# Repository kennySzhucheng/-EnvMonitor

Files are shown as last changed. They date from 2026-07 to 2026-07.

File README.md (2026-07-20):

# EnvMonitor — 智能环境监测站

> STM32F103C8T6 + FreeRTOS + ESP8266 桌面环境监测终端 | 练习项目

一个从零开始搭建的嵌入式 IoT 项目：裸机固件 → FreeRTOS 重构 → KiCad 画板 → 嘉立创打样，走完嵌入式产品全流程。

---

## 📸 实物展示

> ⏳ PCB 已下单，等待到货焊接后补图。

---

## ✨ 功能

| 模块 | 作用 |
|---|---|
| 🌡️ **DHT22** | 温湿度传感器，单总线(1-Wire)通信，精度 ±0.5°C / ±2%RH，挂在 PA0 上 |
| ☀️ **BH1750** | 环境光强度传感器，I²C 接口，0~65535 lux 量程，和 OLED 共用 PB6/PB7 |
| 📏 **HC-SR04** | 超声波测距模块，探测前方物体距离，用于"有人靠近"检测，PB0 发触发信号、PB1 输入捕获回波 |
| 🖥️ **OLED SSD1306** | 0.96 寸 I²C 显示屏，5 页菜单循环切换(温湿度/光照/距离/WiFi/系统信息) |
| 📡 **ESP8266-01S** | WiFi 模块，通过 UART1(PA9/PA10) 走 AT 指令，HTTP GET 方式每 60s 上传一次 ThingSpeak |
| 🚨 **三色 LED** | 红色(高温>35°C)、黄色(湿度<30%)、绿色(有人靠近<30cm)，分别接 PB12/13/14 |
| 🔔 **蜂鸣器** | 5V 有源模块，出现报警条件时由 BuzzerTask 队列驱动蜂鸣 |
| 🎛️ **三按键** | KEY1 页面切换 / KEY2 确认 / KEY3 返回，PA4/5/6，消抖电容 + 10kΩ 外部上拉 |
| ⏱️ **FreeRTOS** | 6 个任务抢占式调度，3 个互斥量保护共享资源，2 条队列做任务间通信 |
| 🛡️ **自定义 PCB** | KiCad 10 设计，80×60mm 双面板，全插件 27 元件，双面 GND 铺铜 |

---

## 🧱 硬件架构

```
                    ┌──────────────────────────────────┐
                    │        STM32F103C8T6 (72MHz)     │
                    │           Blue Pill 核心板         │
                    │                                  │
    DHT22 ──────────┤ PA0 (1-Wire)                     │
    KEY1~3 ─────────┤ PA4/PA5/PA6 (GPIO Input)        │
    ESP8266 ────────┤ PA9/PA10 (USART1, 115200bps)     │
    HC-SR04 ────────┤ PB0(Trig) / PB1(Echo, TIM3_CH4) │
    OLED+BH1750 ────┤ PB6/PB7 (I2C1, 共用总线)          │
    LED_R/Y/G ──────┤ PB12/PB13/PB14 (GPIO Output)     │
    Buzzer ─────────┤ PB15 (GPIO Output, 直连模块IO)    │
                    └──────────────────────────────────┘

    电源: USB 5V → Blue Pill → AMS1117 → 3.3V（全板供电来自 USB）
```

---

## 📐 引脚分配

| 引脚 | 外设 | 功能 |
|---|---|---|
| PA0 | DHT22 | 1-Wire 单总线 |
| PA4/PA5/PA6 | KEY1/KEY2/KEY3 | 按键输入(10kΩ 上拉) |
| PA9/PA10 | ESP8266 | USART1 TX/RX |
| PB0 | HC-SR04 Trig | 触发信号 |
| PB1 | HC-SR04 Echo | TIM3_CH4 输入捕获 |
| PB6/PB7 | OLED + BH1750 | I2C1 SCL/SDA（共用总线） |
| PB12/PB13/PB14 | LED_R/Y/G | 报警指示灯 |
| PB15 | Buzzer | 有源蜂鸣器模块 IO |
| PA13/PA14 | SWDIO/SWCLK | ST-Link 调试（保留） |

---

## 🖥️ 软件架构

```
                    ┌───────────────┐
                    │   FreeRTOS    │
                    │  V10.3.1      │
                    ├───────┬───────┤
                    │ 互斥量 ×3     │  队列 ×2
                    │ I2C / Data   │  Button → Display
                    │ / UART       │  Alarm → Buzzer
                    └───────┴───────┘
                           │
    ┌──────────────────────┼──────────────────────┐
    │                      │                      │
┌───▼──────┐  ┌──────▼─────┐  ┌────────▼───────┐
│SensorTask│  │DisplayTask │  │  CloudTask      │
│ (5s)     │  │ (1s)       │  │  (60s)          │
│ Prio:3   │  │ Prio:2     │  │  Prio:1         │
│          │  │             │  │                 │
│ DHT22    │  │ OLED 5页   │  │ ESP8266 AT指令  │
│ BH1750   │  │ 菜单渲染    │  │ HTTP GET        │
│ HC-SR04  │  │             │  │ ThingSpeak ☁️   │
└──────────┘  └─────────────┘  └─────────────────┘

┌──────────┐  ┌──────────────┐  ┌──────────────┐
│AlarmTask │  │ BuzzerTask   │  │ ButtonTask    │
│ (500ms)  │  │ (事件驱动)    │  │ (20ms)        │
│ Prio:3   │  │ Prio:2       │  │ Prio:2        │
│          │  │              │  │               │
│ 三级报警  │  │ xQueueReceive│  │ 状态机消抖     │
│ 阈值判断  │──▶ 阻塞等待     │  │ 队列发送事件   │
└──────────┘  └──────────────┘  └──────────────┘
```

**任务优先级原则：** 采集 > 报警 > 显示 = 按键 = 蜂鸣 > 上云

---

## 📦 物料清单 (BOM)

### PCB 焊接件（27个）

| 类型 | 规格 | 数量 | 位号 |
|---|---|---|---|
| 排母 | 1×20P 2.54mm | 2 | H1, H2 |
| 排针 | 1×4P 2.54mm | 3 | J2, J3, J4 |
| 排针 | 2×4P 2.54mm | 1 | J5 |
| 排针 | 1×3P 2.54mm | 1 | LS1 |
| 电阻 | 330Ω 1/4W | 3 | R10, R11, R12 |
| 电阻 | 4.7kΩ 1/4W | 3 | R4, R5, R6 |
| 电阻 | 10kΩ 1/4W | 3 | R7, R8, R9 |
| 瓷片电容 | 100nF (104) | 3 | C18, C19, C20 |
| 电解电容 | 100µF/10V | 2 | C21, C22 |
| LED 3mm | 红/黄/绿 | 3 | D2, D3, D4 |
| 轻触开关 | 6×6mm | 3 | SW2, SW3, SW4 |

### 外接模块（7个）

| 模块 | 数量 |
|---|---|
| STM32F103C8T6 Blue Pill | 1 |
| DHT22 温湿度传感器 | 1 |
| GY-302 光照 (BH1750) | 1 |
| OLED 0.96" SSD1306 | 1 |
| HC-SR04 超声波 | 1 |
| ESP8266-01S WiFi | 1 |
| 5V 有源蜂鸣器模块 | 1 |

> 💰 全部物料实际花费约 **90 元**（含 PCB 打样 20 元 + 模块 51 元 + 分立元件 13 元 + 工具 5 元）。完整清单见 `hardware/pcb/EnvMonitor/BOM_EnvMonitor.md`

---

## 🔧 开发环境

| 工具 | 用途 |
|---|---|
| **Keil MDK5** | 固件编译/烧录 |
| **STM32CubeMX** | 引脚配置 + HAL 代码生成 |
| **STM32CubeF1 V1.8.7** | HAL 库 + FreeRTOS 源码 |
| **ST-Link V2** | 调试/烧录器 |
| **KiCad 10.0** | 原理图 + PCB 设计 |
| **ThingSpeak** | IoT 数据可视化云平台 |

### 编译

1. 用 CubeMX 打开 `EnvMonitor.ioc` 重新生成代码（如需要）
2. `EnvMonitor\MDK-ARM\EnvMonitor.uvprojx` → Keil 打开
3. 确认 Include Paths 包含：`Drivers/*`、`App/`、`FreeRTOS/include`、`FreeRTOS/portable/RVDS/ARM_CM3`
4. Build (F7) → 0 Error → Download (F8)

### ThingSpeak 配置

1. 注册 https://thingspeak.com → Create Channel → 4 Fields
2. 将 Write API Key 填入 `esp8266.h` 中的 `THINGSPEAK_API_KEY`
3. 修改 WiFi 账号密码：`esp8266.h` → `WIFI_SSID` / `WIFI_PASS`

---

## 📂 项目结构

```
EnvMonitor/
├── firmware/               ← 固件源码（裸机版 + FreeRTOS版）
│   ├── Core/               HAL 配置 + main.c
│   ├── Drivers/            8 个外设驱动
│   │   ├── DHT22/          温湿度传感器
│   │   ├── BH1750/         光照传感器
│   │   ├── HC_SR04/        超声波测距
│   │   ├── OLED/           SSD1306 显示 + 字库
│   │   ├── ESP8266/        WiFi + ThingSpeak
│   │   ├── LED/            三色指示灯
│   │   ├── Button/         按键(状态机消抖)
│   │   └── Buzzer/         蜂鸣器
│   └── App/                应用层(状态机/菜单/报警)
│
├── EnvMonitor/             ← Keil + CubeMX 工程
│   ├── Core/               CubeMX 生成(含 main.c)
│   ├── Drivers/            同上 8 驱动 + ST HAL 库
│   ├── App/                6 个 FreeRTOS 任务 + task_shared
│   ├── MDK-ARM/            Keil 工程文件
│   └── EnvMonitor.ioc      CubeMX 项目
│
├── hardware/pcb/EnvMonitor/ ← KiCad PCB 设计
│   ├── EnvMonitor.kicad_*  工程文件
│   ├── BOM_EnvMonitor.md   完整物料清单
│   ├── EnvMonitor_Gerber_Full.zip  嘉立创打样包
│   ├── gerber/             Gerber 源文件(11层)
│   └── analysis/           出厂分析报告
│
└── docs/                   项目文档
    ├── 接线图.md            引脚分配表
    ├── 开发日志.md           设计决策 + 踩坑记录
    ├── 原理图讲解.md
    ├── KiCad入门讲解.md
    ├── PCB布局布线入门.md
    └── FreeRTOS入门讲解.md
```

---

## 📝 开发历程

| 阶段 | 内容 | 状态 |
|---|---|---|
| P0 | 项目规划 + 器件采购 | ✅ |
| P1-P6 | 裸机固件：8 驱动 + 5 页菜单 + 报警 + 上云 | ✅ |
| P7 | FreeRTOS 6 任务重构 | ✅ |
| P8 | KiCad 原理图 → 布局 → 布线 → DRC → Gerber | ✅ |
| P9 | 嘉立创打样 → 焊接 → 联调 → 发布 | 🔄 |

### 🔥 关键问题与解决

> 完整记录见 [`docs/开发日志.md`](docs/开发日志.md)

| # | 问题 | 根因 | 解决 |
|---|---|---|---|
| 1 | Keil 编译 `cannot open oled.h` | **循环包含**：`main.h` ↔ 驱动 `.h` 互相 include | 驱动 `.h` 改用 `stm32f1xx_hal.h`，`.c` 先 include `main.h` |
| 2 | FreeRTOS 链接 4 个 Undefined | 调试钩子未实现，V10.x 默认开启 | 关闭 MallocFailedHook / StackOverflowHook / StaticAllocation |
| 3 | KiCad 标签放空白处 | 标签必须附着在导线上，否则 = 独立网络 | 标签放在导线段上，高亮确认后放下 |
| 4 | 按键消抖电路出错 | R/C/SW/MCU 未在同一节点，MCU 脚孤悬 | 四者交汇一点，SW 另一脚 → GND |
| 5 | 14 个元件 PCB 导入失败 | 封装名缺脚距后缀（如 `_P2.54mm_Vertical`） | 编辑 `.kicad_sch` 批量替换封装名 |
| 6 | 蜂鸣器方案紧急变更 | 实物 3 脚模块 vs 原理图 2 脚+NPN 驱动 | 换 3 脚排针，删 Q1/R13/R14/D5，MCU 直连 |
| 7 | GND 铺铜 DRC 仍报未连接 | 铺铜只创建轮廓，没填充 | 按 **B** 键填充所有区域 |
| 8 | Keil 缺 `configUSE_16_BIT_TICKS` | FreeRTOS V10.x 新增必选宏 | `FreeRTOSConfig.h` 补定义 |
| 9 | 面包板测试失败，跳过直接上 PCB | STM32 内部上拉 ~40kΩ 太弱，面包板寄生干扰导致引脚浮空、按键读值随机跳变 | 外部 10kΩ 上拉 + PCB 实体焊点可彻底解决，不在面包板上浪费时间 |

### 💡 设计决策

| 决策 | 选择 | 理由 |
|---|---|---|
| RTOS | FreeRTOS 原生 API | 不依赖 CMSIS-RTOS 封装，社区资源多 |
| WiFi | ESP8266 AT 指令 + HTTP GET | ThingSpeak 原生支持，无需 MQTT broker |
| PCB | 全插件 THT + 模块化 | 新手可焊，Blue Pill 已有电路不重复画 |
| EDA | KiCad 10.0 | 开源免费，S-expression 格式透明 |
| I2C | OLED + BH1750 同总线 | 地址不同(0x3C/0x46)，不冲突，省 GPIO |

### 📚 学习历程

这个项目最大的收获不是做出来一个东西，而是 **5 天里从零啃下了 4 块硬骨头**：

| 技能 | 项目前 | 项目后 |
|---|---|---|
| **STM32 开发方式** | 只会标准库，没碰过 HAL | CubeMX 配置 + HAL 库驱动开发，理解句柄/初始化回调 |
| **FreeRTOS** | 完全不了解 | 6 任务抢占式调度，互斥量/队列/软件定时器，SysTick 三分天下 |
| **PCB 设计** | 零基础，没画过板 | KiCad 10.0 原理图→封装→布局→布线→铺铜→DRC→Gerber 全流程 |
| **项目工程化** | 单文件裸机循环 | 三层架构(Drivers/App/Core)，Git 版本控制，README 文档规范 |

> 💡 KiCad 入门借助了 Claude Code 的 KiCad Skill 辅助分析，但具体画板——元件摆放、走线、铺铜——还是得自己动手一刀一刀画，其实我以为可以让ai帮我解决排线问题，实则搞半天还是得自己来而且第一次画确实特别乱，没有经验，更改了很多遍

---

## 📄 许可

MIT License

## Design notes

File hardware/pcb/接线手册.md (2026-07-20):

# 🔌 EnvMonitor 原理图接线手册

> 按组逐行连线。已标出每个元件的引脚。用 W 键画线。

---

## 第1组：电源

```
+5V 标签 ──────── C21 (正极 +)
C21 (负极 -) ──── GND
+3.3V 标签 ────── C22 (正极 +)
C22 (负极 -) ──── GND
然后把画面上所有的 GND 符号连在一起！
```

---

## 第2组：I²C上拉 + 模块接口

### 2a. 上拉电阻
```
+3.3V ─── R4(上端)       R4(下端) ─── J3 的 pin2 (SCL)
+3.3V ─── R5(上端)       R5(下端) ─── J3 的 pin3 (SDA)
+3.3V ─── R6(上端)       R6(下端) ─── J2 的 pin2 (DATA)
```

### 2b. 模块供电
```
+3.3V ─── J2 的 pin1
+3.3V ─── J3 的 pin1
 GND  ─── J2 的 pin4
 GND  ─── J3 的 pin4
```

---

## 第3组：HC-SR04 超声波 + ESP8266

### 3a. HC-SR04 (J4)
```
+5V ─── J4 的 pin1 (VCC)
GND ─── J4 的 pin4 (GND)
```
> pin2(Trig)和 pin3(Echo)的信号线等核心板那组时再连

### 3b. ESP8266-01S (J5)
```
+3.3V ─── J5 的 pin1 (VCC)
+3.3V ─── J5 的 pin3 (CH_PD/EN, 必须拉高才能工作)
 GND  ─── J5 的 pin8 (GND)
```
> pin5(TX)和 pin6(RX)等核心板那组时连

---

## 第4组：按键 (3路完全一样, 做一路后复制)

### KEY1 通道
```
+3.3V ─── R7(上端)
R7(下端) ─┬─ SW2(上端)     SW2(下端) ─── GND
           └─ C18(上端)    C18(下端) ─── GND
```
> R7下端分叉接SW2和C18的交点，拉出标签 "PA4_KEY1"

### KEY2 通道
```
+3.3V ─── R8(上端)
R8(下端) ─┬─ SW3(上端)     SW3(下端) ─── GND
           └─ C19(上端)    C19(下端) ─── GND
```
> R8下端 → 标签 "PA5_KEY2"

### KEY3 通道
```
+3.3V ─── R9(上端)
R9(下端) ─┬─ SW4(上端)     SW4(下端) ─── GND
           └─ C20(上端)    C20(下端) ─── GND
```
> R9下端 → 标签 "PA6_KEY3"

---

## 第5组：LED指示灯 (3路一样)

```
标签"PB12_LEDR" → R10(上端) → R10(下端) → D2(正极/三角那边) → D2(负极) → GND
标签"PB13_LEDY" → R11(上端) → R11(下端) → D3(正极/三角那边) → D3(负极) → GND
标签"PB14_LEDG" → R12(上端) → R12(下端) → D4(正极/三角那边) → D4(负极) → GND
```

---

## 第6组：蜂鸣器驱动

```
标签"PB15_BUZZ" → R13(左端) → R13(右端) → Q1 的 B (基极, 中间脚)
                                            └── R14(上端)
                                                R14(下端) → GND

+5V ─── D5(负极, 有横线那端)
         │
         └── Q1 的 C (集电极, 一般是上脚)
              │
              └── LS1 的 pin1 (+)

Q1 的 E (发射极, 下脚) → GND
LS1 的 pin2 (-) → GND
```

---

## 第7组：核心板插座 (最后连!)

把所有标签连到核心板对应的引脚：

| 标签名 | 连到核心板引脚 |
|---|---|
| PA0_DHT22 | H1/H2 的 PA0 |
| PB6_SCL | H1/H2 的 PB6 |
| PB7_SDA | H1/H2 的 PB7 |
| PB0_TRIG | H1/H2 的 PB0 |
| PB1_ECHO | H1/H2 的 PB1 |
| PA9_TX | H1/H2 的 PA9 |
| PA10_RX | H1/H2 的 PA10 |
| PA4_KEY1 | H1/H2 的 PA4 |
| PA5_KEY2 | H1/H2 的 PA5 |
| PA6_KEY3 | H1/H2 的 PA6 |
| PB12_LEDR | H1/H2 的 PB12 |
| PB13_LEDY | H1/H2 的 PB13 |
| PB14_LEDG | H1/H2 的 PB14 |
| PB15_BUZZ | H1/H2 的 PB15 |
| +5V | H1/H2 的 5V 引脚 |
| +3.3V | H1/H2 的 3.3V 引脚 |
| GND | H1/H2 的 GND 引脚 |

---

## ⚡ 小技巧

- **W键** = 开始画线, 点起点 → 点终点
- **L键** = 添加标签, 输入标签名
- **Delete** = 删除选中的东西
- **Ctrl+Z** = 撤销
- 画完一组按 **Ctrl+S** 保存

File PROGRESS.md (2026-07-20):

# 📋 项目进度记录

> ⚠️ **重要：每次关闭对话框前，请在下方记录当天的进度。**
> 下次打开时，从这里接着做。

---

## 📌 项目概述

| 项目 | 智能环境监测与物联网控制站 |
|---|---|
| 主控 | STM32F103C8T6 |
| 预算 | 约 76 元 |
| 目标 | 桌面环境终端 + WiFi数据上云 + GitHub开源 |

---

## 🗂️ 项目结构

```
电路实训/
├── PROGRESS.md          ← 进度清单（你在这里）
├── README.md            ← GitHub 项目主页
├── .gitignore
├── docs/
│   ├── 接线图.md         ← 引脚分配表
│   └── 开发日志.md       ← 关键对话 + 踩坑记录 + 设计思路
├── EnvMonitor/          ← CubeMX + Keil 工程（当前工作目录）
│   ├── Core/            ← HAL 配置 + main.c
│   ├── Drivers/         ← 8个传感器/外设驱动
│   ├── App/             ← 应用层
│   └── MDK-ARM/         ← Keil 工程文件
├── firmware/            ← 固件源码副本（与 EnvMonitor 同步）
├── hardware/pcb/        ← PCB 设计（后续）
└── assets/              ← 图片/素材
```

---

## 🔢 开发阶段

| 阶段 | 状态 | 内容 | 开始 | 完成 |
|---|---|---|---|---|
| P0 | ✅ 完成 | 项目规划 + 器件采购 | 2026/07/15 | 2026/07/15 |
| P1 | 📝 代码就绪 | GPIO 基础：LED亮灭、蜂鸣器、按键 | 2026/07/16 | 2026/07/16 |
| P2 | 📝 代码就绪 | OLED 驱动：I2C + SSD1306，显示文字 | 2026/07/16 | 2026/07/16 |
| P3 | 📝 代码就绪 | 传感器驱动：DHT22(1-Wire) + BH1750(I2C) | 2026/07/16 | 2026/07/16 |
| P4 | 📝 代码就绪 | OLED 多页面菜单 + 按键切换 | 2026/07/16 | 2026/07/16 |
| P5 | 📝 代码就绪 | HC-SR04 超声波 + 蜂鸣器报警逻辑 | 2026/07/16 | 2026/07/16 |
| P6 | 📝 代码就绪 | ESP8266 WiFi + HTTP 数据上云 | 2026/07/16 | 2026/07/16 |
| P7 | ✅ 完成 | FreeRTOS 任务重构 | 2026/07/16 | 2026/07/17 |
| P8 | ✅ 完成 | PCB 设计 + Gerber 导出 | 2026/07/17 | 2026/07/20 |
| P9 | 🔄 进行中 | 整机联调 + GitHub README + 项目发布 | 2026/07/20 | - |

---

## 📝 进度日志

### 2026-07-15 — 项目启动

- [x] 确定项目方案：智能环境监测与物联网控制站
- [x] 完成器件清单，下单购买
- [x] 创建项目文件夹结构
- [ ] 待器件到货
- [x] 详细设计思路 → 见 `docs/开发日志.md`

### 2026-07-16（上） — 固件代码全部完成

- [x] Core：HAL配置、全局头文件、main.c（26个源文件覆盖 P1-P6）
- [x] Drivers：LED / Button / Buzzer / OLED(含字库) / DHT22 / BH1750 / HC-SR04 / ESP8266
- [x] App：状态机 / 5页面菜单 / 三级报警逻辑
- [x] 各驱动设计要点 → 见 `docs/开发日志.md`

### 2026-07-16（下） — CubeMX 工程整合 + Keil 编译通过 ✅

- [x] CubeMX 配置引脚/时钟/外设 → 生成 MDK-ARM 工程
- [x] 修正 gpio.c（PA0→开漏、按键→上拉、补 LED 引脚）
- [x] 修正 tim.c（Prescaler=71, Filter=4）
- [x] 替换 main.h + main.c
- [x] 复制 Drivers + App 到工程
- [x] 修复循环包含（11个.h → stm32f1xx_hal.h，11个.c → 加 main.h）
- [x] 补回 SystemClock_Config()
- [x] **Keil 编译通过，0 Error！**
- [x] 踩坑记录（7个关键问题）→ 见 `docs/开发日志.md`

---

### 2026-07-17 — P7 FreeRTOS 任务重构 ✅ 完成

- [x] 从 STM32Cube F1 固件包提取 FreeRTOS V10.3.1 内核源码
- [x] 创建 FreeRTOSConfig.h（6KB堆、5级优先级、1ms tick）
- [x] 创建 task_shared 共享资源模块（3互斥量 + 2队列）
- [x] 编写 6 个 RTOS 任务：Sensor / Display / Cloud / Alarm / Button / Buzzer
- [x] 重写 main.c 为 FreeRTOS 调度器启动
- [x] 修改 stm32f1xx_it.c（SVC/PendSV→FreeRTOS, SysTick→HAL+RTOS三合一）
- [x] 精简 app.c/app.h 为共享类型定义
- [x] Keil 工程配置（8个 FreeRTOS 源文件 + 7个任务文件 + 3条 include 路径）
- [x] 修复编译问题：补 configUSE_16_BIT_TICKS + configSUPPORT_STATIC/DYNAMIC_ALLOCATION
- [x] 修复链接问题：关 MallocFailedHook + StackOverflowHook + StaticAllocation 钩子
- [x] **Keil 编译通过，0 Error！**

### 编译踩坑

| 问题 | 报错 | 解决 |
|---|---|---|
| 缺 configUSE_16_BIT_TICKS | `#error Missing definition` | V10.x 新增宏，FreeRTOSConfig.h 补上 |
| 静态分配未关 | `Undefined vApplicationGetIdleTaskMemory` | configSUPPORT_STATIC_ALLOCATION=0 |
| 钩子未实现 | `Undefined vApplicationMallocFailedHook` 等 | MallocFailedHook/StackOverflowHook 全关 |
| 栈检测方法2需钩子 | `Undefined vApplicationStackOverflowHook` | configCHECK_FOR_STACK_OVERFLOW=0 |

### Keil 工程配置记录

> 已在 Keil 中完成：
> - 分组 FreeRTOS/Kernel: tasks.c, queue.c, list.c, timers.c, event_groups.c, croutine.c
> - 分组 FreeRTOS/Port: port.c (RVDS/ARM_CM3), heap_4.c (MemMang)
> - 分组 App/Tasks: 7 个 task_*.c 文件
> - Include 路径: Drivers/FreeRTOS/include, portable/RVDS/ARM_CM3, Core/Inc

### 2026-07-17（下）— P8 PCB 原理图设计 🔄

- [x] 方案选型：确定方案B（全插件/模块化），Blue Pill 核心板通过排母连接
- [x] 工具选型：选择 KiCad 10.0（非立创EDA），Python 脚本辅助生成
- [x] 31 个元件全部放置完毕（11电阻 + 5电容 + 3LED + 1二极管 + 1三极管 + 3按键 + 1蜂鸣器 + 6连接器）
- [x] 7 组电路逐组布局：电源 → I2C上拉 → 模块接口 → 按键 → LED → 蜂鸣器 → 核心板插座
- [x] 15 条信号网络全部与引脚分配表对照验证通过
- [x] ERC 从 82 错误逐轮降至 6 错误
- [x] 踩坑记录（4个关键问题）→ 见 `docs/开发日志.md`

### PCB 原理图踩坑

| 问题 | 现象 | 解决 |
|---|---|---|
| 标签悬空 | KEY/DHT22等标签在空白处，网络分裂 | 标签必须放在导线上，KiCad 通过同名标签合并网络 |
| 按键电路拓扑错误 | R和C在开关两边，MCU脚孤悬读不到电压 | R下端 + C上端 + SW一脚 + MCU标签 = 同一交汇点；SW另一脚 → GND |
| 消抖电容未接地 | C18-C20 pin2 悬空，RC滤波不工作 | 电容负极直接连 GND，不可用 No-Connect |
| 开关角色反转 | 开关夹在 R+C 交汇点和 MCU 之间 | 开关一脚接交汇点，另一脚接 GND；MCU 直接挂在交汇点上 |

### 原理图→PCB 导入

- [x] 31 个元件封装全部分配（11电阻 + 5电容 + 3LED + 1二极管 + 1三极管 + 3按键 + 1蜂鸣器 + 6连接器）
- [x] 修复 fp-lib-table 库表配置（Button_Switch_TH 拼写错误 → Button_Switch_THT）
- [x] 修复 14 个封装名不匹配（电阻缺脚距参数 + 按键尺寸 5x5→6mm）
- [x] 成功导入 PCB Editor，31/31 元件到位，85 条网络飞线就绪
- [ ] ⬜ 画板框（Edge.Cuts 层，建议 80×60mm）
- [ ] ⬜ 元件布局摆放
- [ ] ⬜ 布线 + 铺铜 + DRC

### KiCad 封装踩坑

| 问题 | 原因 | 解决 |
|---|---|---|
| 14 个元件导入失败 | 原理图封装名与库中实际文件名不匹配 | 电阻补全脚距参数 `_P2.54mm_Vertical`；按键改为 `SW_PUSH_6mm` |
| fp-lib-table 配置 | 手动添加库时昵称拼错（少写一个T） | 删掉重复项，直接用 KiCad 自带模板库表 |

> ⚠️ 对话框意外关闭导致部分 PCB 开发记忆丢失，本次日志基于项目文件逆向还原。
> 📚 新增文档：`docs/KiCad入门讲解.md`、`docs/原理图讲解.md`

### 2026-07-18（上）— 器件到货核查 ✅

- [x] 全部 16 项器件到货，逐项核对通过
- [x] 核心板 + 面包板 + 跳线就绪
- [ ] ⬜ 面包板分步试验（Step1→4）
- [ ] ⬜ PCB 布局布线

### 📦 到货器件清单

#### 🔴 核心板 & 基础
| 物品 | 数量 | 备注 |
|---|---|---|
| STM32F103C8T6 Blue Pill | 1 | 蓝色PCB，板上含STM32+晶振+AMS1117+USB+复位 |
| 面包板 | 1 | 白色，830孔 |
| 杜邦跳线 | 若干 | 公母头均有 |

#### 🟢 外接模块（6个全齐）
| 模块 | 数量 | 接口 |
|---|---|---|
| DHT22 温湿度传感器 | 1 | 4Pin |
| GY-302 光照传感器 (BH1750) | 1 | I²C |
| OLED 0.96" SSD1306 黄蓝双色 | 1 | I²C 4P |
| HC-SR04 超声波测距模块 | 1 | 4Pin |
| ESP8266-01S WiFi模块 (安信可) | 1 | 2x4Pin |
| 5V有源蜂鸣器模块 | 1 | 3Pin |

#### 🟡 分立元件
| 物品 | 数量 | 用途 |
|---|---|---|
| 1/4W金属膜电阻包 (30种x10) | 1盒 | 含4.7kΩ/10kΩ/330Ω/1kΩ |
| S8050 三极管 TO-92 | 20只 | 蜂鸣器驱动(仅需1) |
| LED 红色 3mm | 10只 | 高温报警 |
| LED 黄色 3mm | 10只 | 湿度报警 |
| LED 绿色 3mm | 10只 | 靠近检测 |
| 轻触开关 6x6x4.3mm | 20只 | KEY1/KEY2/KEY3(仅需3) |
| 排针 1x40P 直针 | 1条 | 可自由折断 |
| 排母 1x40P 排座 | 1条 | 掰成2条1x20P焊核心板 |
| USB转TTL HW-597 | 1 | ESP8266调试/烧录 |

#### 🔵 待补买（不影响面包板测试）
| 物品 | 数量 | 用途 |
|---|---|---|
| 100nF 瓷片电容 (104) | 3 | 按键消抖 |
| 100µF/16V 电解电容 | 1 | 5V滤波 |
| 100µF/10V 电解电容 | 1 | 3.3V滤波 |
| 1N4148 二极管 DO-35 | 1 | 蜂鸣器续流(模块已有驱动可省) |

> 📝 **核对时间**: 2026-07-18，通过 15 张照片逐张视觉识别 + BOM 对照
> 💡 **BH1750备注**: 买的 GY-302 而非 GY-30，芯片相同，不影响使用
> 💡 **蜂鸣器备注**: 买的是模块版，自带驱动电路，可跳过 Q1/R13/R14/D5 直连 GPIO

### 2026-07-18（下）— 面包板 GPIO 测试 ⚠️

- [x] 面包板搭建 Blue Pill + 3 LED + 3 按键电路
- [x] ST-Link V2 烧录链路正常
- [x] LED 输出正常（PB12/PB13/PB14 闪烁 OK）
- [ ] ⚠️ 按键输入失败：PA4/PA5/PA6 内部上拉(~40kΩ)在面包板上不可靠
- [ ] ⚠️ 引脚浮空导致电平随机跳变，按键读取不稳定

### 🔬 踩坑记录

| 问题 | 现象 | 结论 |
|---|---|---|
| 按键引脚浮空 | PA4/PA5/PA6 读值随机，LED 闪烁后全亮 | STM32 内部 ~40kΩ 上拉太弱，面包板干扰大 |
| 外部 10kΩ 上拉 | 加了后仍不稳定 | 面包板插孔接触不良是根本原因 |
| 电平反转尝试 | 改用 PULLDOWN + HIGH 触发，现象相同 | 面包板寄生干扰无法消除 |

### 💡 教训 & 决策

> 面包板测试卡在 GPIO 输入浮空问题，耗时 2h+ 无进展。**决定跳过面包板完整测试，PCB 上直接验证。** PCB 有实体焊点+外部 10kΩ 上拉(R7/R8/R9)，不存在接触不良/浮空问题。

- [x] 测试固件已删除，main.c 恢复为完整 FreeRTOS 版本
- [ ] ⬜ 下一步：PCB 布局布线 → 打样焊接 → 板上联调

---
---
### 2026-07-19 — PCB 布局启动 🔄

- [x] 板框已画：Edge.Cuts 层 80×60mm 矩形 ✅
- [x] Blue Pill 实物测量：排针间距 ~15.5mm，板全长 ~53mm
- [x] 布局方向确定：Blue Pill 横向放置（53mm < 80mm板宽）
- [x] H1/H2 排母 90° 旋转，横向排列
- [x] 确定工作分工：软件由我验证，硬件给提示、用户自己动手学习
- [ ] ⬜ 元件布局摆放（31个）
- [ ] ⬜ 布线 + 铺铜 + DRC
- [ ] ⬜ 补买电容 + 1N4148

### 🗺️ PCB 布局方案

```
板框 80×60mm，Blue Pill 横放:
  ┌──────────────────────────────┐
  │  J2  J3  J4  J5  LS1       │  ← 上排: 模块接口
  │  (DHT22/OLED+BH/HC-SR04/   │
  │   ESP8266/蜂鸣器)           │
  │                              │
  │  H1 ════ Blue Pill ════ H2 │  ← 中央横放 (Y≈69~92)
  │  间距 ~15.5mm                │
  │                              │
  │  电阻/电容/三极管 散布        │
  │                              │
  │  SW2 SW3 SW4  D2 D3 D4     │  ← 下排: 按键 + LED
  └──────────────────────────────┘
```

### 💡 分工模式确立

> 软件（固件/USB协议/编译）→ 我来确认无误
> 硬件（PCB布局/焊接/接线）→ 我给提示，用户动手学习

### 2026-07-19（上）— PCB 元件布局完成 🔄

- [x] H1/H2 方向确认：竖放→横放，用户调整为底部横放
- [x] H1/H2 封装确认：2×20 双排排母，H1用RowB(偶)/H2用RowA(奇)，内侧排间距15.5mm
- [x] 31个元件封装与实物逐项核对通过
- [x] 供电方案确认：Blue Pill USB供电，无需额外电源模块
- [x] 元件布局分区：电阻(底)→滤波+WiFi+LED(中)→Blue Pill→按键+电容+DHT22(顶)
- [x] 微调：C19移到SW3旁边，R5移到R4旁边
- [x] 下一步：+5V电源线布线 → +3.3V → 信号线 → 铺铜 → DRC

### 💡 今日经验

> Blue Pill 自身 USB 口就是电源，PCB 不需要额外电源电路。USB 5V→Blue Pill→5V引脚+AMS1117→3.3V引脚，整板供电满足。

---

### 2026-07-19（下）— PCB 布线完成 ✅

- [x] +5V 电源走线（H2 Pad35 → J4, C21, LS1）
- [x] +3.3V 电源走线（H1.6 + H2.39 → 11个负载）
- [x] 全部 24 条信号网路布线
- [x] B.Cu + F.Cu 双面 GND 铺铜
- [x] DRC 检查：0 错误 0 未连接
- [x] KiCad Skill 分析器辅助验证：151 脚逐脚比对通过

### 💡 布线经验

> 0.2mm 线宽对于本板电流（峰值 ~350mA）足够，但电源线建议 0.5mm 更稳妥。双面铺铜关键步骤：画铺铜区域 → Net 选 GND → **按 B 填充** → 保存。填充后 GND 焊盘自动连通，不需要手动一根根走线。

---

### 2026-07-20（凌晨）— 蜂鸣器方案变更 ✅

- [x] 发现蜂鸣器实物为 3 脚有源模块（自带驱动），与 PCB 上 2 脚+三极管驱动方案不兼容
- [x] 原理图改动：删 Q1(S8050) / R13(1k) / R14(10k) / D5(1N4148)
- [x] LS1 改为 3 脚排针 `PinHeader_1x03`（VCC→+5V / GND→GND / IO→BUZZ 直连 MCU）
- [x] 元件数从 31 减到 27，蜂鸣器电路大幅简化
- [x] 重新布线 + 铺铜 + DRC：0 错误
- [x] 原理图↔PCB 交叉分析：0 差异
- [x] 备份旧版到 `backup_20260720/`
- [x] 导出 Gerber 文件，准备嘉立创打样

### 💡 蜂鸣器教训

> 采购前要确认模块接口：有源蜂鸣器模块（3脚，VCC/GND/IO）和裸蜂鸣器（2脚）接口完全不同。买模块的好处是不需要自己搭三极管驱动电路，一个 IO 口直连即可。以后买器件时先拍照片确认引脚数再画封装。

### 💡 网路标签一致性

> KiCad 中 `BUZZ` 和 `/BUZZ` 是两个不同网路。原理图中全局标签加不加 `/` 前缀要保持一致。踩坑：改了 LS1 符号后标签弄混，导致 MCU 和蜂鸣器属于不同网路——交叉分析发现后修复。

---

## 🛑 下次接着做

>
> **当前状态（2026-07-20 晚）：**
> - ✅ 器件全部到货
> - ✅ 固件 P0-P7 Keil 编译 0 Error
> - ✅ P8 PCB: 原理图→布局→布线→DRC→Gerber, 嘉立创已下单
> - ✅ GitHub: 仓库已创建 + 5次提交推送 (README含BOM/踩坑/学习历程)
> - ✅ ThingSpeak: 已注册, API Key + WiFi 配置已写入本地固件
> - ✅ ESP8266 模块测试: 全部 AT 指令通过, HTTP 数据上云 200 OK (2026/07/20)
> - ⬜ P9: 等板到货 → 焊接 → 上电联调 → 拍照补 README
>
> **下次第一件事：**
> 等 PCB 到货后 → 焊接 27 个元件 → 上电 → 烧录固件 → 整机联调

### 2026-07-20（晚）— ESP8266 模块测试 ✅

- [x] CH340 供电坑：板载 3.3V (~100mA) 带不动 ESP8266 (>300mA 峰值)，灯闪掉线
- [x] 解决：Blue Pill 3.3V (AMS1117 800mA) 独立供电，CH340 只接 TX/RX/GND
- [x] AT 基础通信、WiFi 扫描、WiFi 连接 全部 OK
- [x] HTTP GET 上送 ThingSpeak：HTTP/1.0 → Status 200 OK → Field1=25 验证通过
- [x] ThingSpeak 网站确认数据点写入成功
>

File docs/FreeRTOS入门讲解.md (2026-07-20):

# 🎓 FreeRTOS 入门讲解 — 以环境监控器项目为例

> 今天我们把一个裸机程序（while(1)大循环）改成了 FreeRTOS 多任务架构。
> 这篇文档用人话解释：到底做了什么、为什么要这么做、每个概念是什么意思。

---

## 一、裸机 vs RTOS：一句话理解

### 裸机程序（昨天之前的样子）

```c
while (1) {
    if (过了5秒)  采集传感器();
    if (过了1秒)  刷新屏幕();
    if (过了60秒) 上传数据();
    if (过了半秒) 检查报警();
    扫描按键();
    蜂鸣器滴答();
}
```

就像一个**单线程的厨房**——你一个人洗菜、切菜、炒菜、装盘，全自己干。一个锅糊了也得等手上切完再说。

### RTOS 程序（今天改完的样子）

```
任务1: 每5秒采集传感器   (优先级3，高)
任务2: 每半秒检查报警    (优先级3，高)
任务3: 每1秒刷新屏幕     (优先级2，中)
任务4: 每20ms扫描按键    (优先级2，中)
任务5: 有指令时响蜂鸣器   (优先级2，中)
任务6: 每60秒上传云端    (优先级1，低)
```

就像雇了**6 个厨师**，各干各的。炒菜的炒菜，切菜的切菜，互不耽误。主厨（调度器）决定谁先用灶台。

---

## 二、核心概念，逐个击破

### 2.1 任务（Task）

**是什么**：一个独立的、永远在循环的函数。

```c
void SensorTask_Run(void *pvParameters) {
    while (1) {
        采集传感器();
        vTaskDelay(5000);  // 睡5秒，不占CPU
    }
}
```

**关键认知**：任务函数**永远不会 return**。它就像一个小 while(1)，一直在跑。

**vTaskDelay 和裸机 delay 的区别**：
- `HAL_Delay(1000)` → CPU 死等 1 秒，期间啥也不干
- `vTaskDelay(1000)` → 这个任务睡 1 秒，CPU 去跑其他任务

这就是 RTOS 最核心的价值：**等待的时候不浪费 CPU**。

---

### 2.2 优先级（Priority）与抢占

**规则：数字越大优先级越高。高优先级的任务就绪时，立即抢走 CPU。**

```
时间线 ──────────────────────────────────────────→

CloudTask(优先级1):   [=====上传数据=====>
                                   ↑
SensorTask(优先级3):              [采]  ← 抢占！CloudTask 被暂停
                                   ↓
CloudTask(优先级1):                    [=====继续上传=====>
```

**所以**：传感器采集（优先级3）绝不会被云端上传（优先级1）耽搁。反过来，上传时如果传感器要干活，上传会被暂停。

我们的设计逻辑：
- 传感器和报警 = 最高优先级（数据不能丢，报警不能晚）
- 屏幕和按键 = 中等（人眼感觉不到几十ms的延迟）
- 云端上传 = 最低（网络本来就慢，等一会无所谓）

---

### 2.3 互斥量（Mutex）— 共享资源的"门锁"

**问题场景**：OLED 和 BH1750 光照传感器共用 I2C 总线（两根线 PB6/PB7）。

```
DisplayTask:  [正在写OLED屏幕数据...>
SensorTask:       [突然想读BH1750光照...>
                  ↑ 冲突！两根线上同时有两种数据，全乱套
```

**解决方案**：互斥量 = 厕所门锁。

```c
// DisplayTask 中：
xSemaphoreTake(I2C_Mutex);   // 🔒 锁门，拿钥匙
OLED_显示数据();              // 安全使用 I2C
xSemaphoreGive(I2C_Mutex);   // 🔓 开门，还钥匙

// SensorTask 中：
xSemaphoreTake(I2C_Mutex);   // 🔒 等钥匙（如果 DisplayTask 在用就排队）
BH1750_读光照();              // 安全使用 I2C
xSemaphoreGive(I2C_Mutex);   // 🔓 还钥匙
```

**一句话**：谁拿到锁谁用，用完了还回去。别人想用就排队等。

我们的项目有 3 把锁：
| 锁名 | 保护什么 | 谁在用 |
|---|---|---|
| I2C_Mutex | PB6/PB7 总线 | DisplayTask(OLED) + SensorTask(BH1750) |
| Data_Mutex | g_sensorData 全局变量 | 写:SensorTask / 读:Display+Alarm+Cloud |
| UART_Mutex | USART1 串口 | CloudTask(上云) + DisplayTask(WiFi重连) |

---

### 2.4 队列（Queue）— 任务间的"传纸条"

**问题场景**：ButtonTask 发现按键被按下，但 DisplayTask 才负责处理按键逻辑。怎么通知它？

**裸机做法**：全局变量 `g_button_pressed = 1`，DisplayTask 轮询检查。

**RTOS 做法**：队列 = 传送带。

```c
// ButtonTask: 往队列里塞纸条
uint8_t msg = KEY1_PRESSED;
xQueueSend(ButtonQueue, &msg, 0);  // 塞进去，不等

// DisplayTask: 从队列里取纸条
uint8_t msg;
if (xQueueReceive(ButtonQueue, &msg, 0) == pdTRUE) {
    处理按键(msg);  // 收到纸条了！
}
```

**好处**：
- 不会丢事件（裸机全局变量可能被覆盖）
- 先进先出（先按的键先处理）
- 队列空了接收方就跳过（不阻塞）

我们的项目有 2 条队列：
| 队列名 | 谁发 | 谁收 | 传什么 |
|---|---|---|---|
| ButtonQueue | ButtonTask | DisplayTask | 按键事件 |
| BuzzerQueue | AlarmTask | BuzzerTask | 蜂鸣次数/时长 |

---

### 2.5 调度器（Scheduler）— 大管家

**启动调度器**：

```c
vTaskStartScheduler();  // 这行代码之后，main() 永远不会再往下走了
```

调度器一旦启动：
1. 检查所有任务的优先级和状态
2. 挑优先级最高的就绪任务运行
3. 定时（1ms tick）检查是否需要切换任务
4. 任务主动 `vTaskDelay()` 时切换到其他任务

**SysTick 定时器**就是调度器的"心跳"。每 1ms 产生一次中断，调度器在中断里判断"要不要换个人干活"。

---

## 三、今天的迁移做了什么

### 改之前的 main.c：

```
初始化 → while(1) { 一堆 if(到时间了) }  ← 30行
```

### 改之后的 main.c：

```
初始化 → 创建6个任务 → vTaskStartScheduler()  ← 从此 CPU 被 RTOS 接管
```

### 每个"到时间了就干"变成了独立任务：

| 裸机写法 | RTOS 写法 |
|---|---|
| `if (过了5秒) APP_SampleSensors()` | SensorTask 独立运行，vTaskDelayUntil 精确每 5 秒 |
| `if (过了半秒) ALARM_Check()` | AlarmTask 独立运行 |
| `每次循环 Button_Scan()` | ButtonTask 每 20ms 精准扫描 |
| `每次循环 Buzzer_Tick()` | BuzzerTask 阻塞等待指令（零 CPU 开销） |

---

## 四、SysTick 的三合一魔法

今天最关键的一个修改在 `stm32f1xx_it.c` 的 SysTick_Handler：

```c
void SysTick_Handler(void) {
    HAL_IncTick();              // ① HAL 库需要（HAL_Delay 等）
    g_sysTick++;                // ② 我们自己的毫秒计数
    xPortSysTickHandler();      // ③ FreeRTOS 的任务调度时钟
}
```

**SysTick 就像一个 1ms 响一次的闹钟**，响了之后三个"室友"各干各的：
- HAL 库更新自己的计数器
- 我们更新 g_sysTick
- FreeRTOS 检查要不要切换任务

重点是那句 `if (调度器还没启动) 别调 FreeRTOS`——调度器启动前内核结构还没初始化，调了直接死机。

---

## 五、SVC 和 PendSV 是干嘛的

这两个是 Cortex-M3 内核级的"特权中断"，FreeRTOS 独占使用，我们不用管。

**SVC（系统服务调用）**：启动第一个任务时用。FreeRTOS 通过它设置栈指针（MSP→PSP 切换），然后跳转到第一个任务的代码。

**PendSV（可挂起系统调用）**：每次切换任务时用。它把所有寄存器的值保存到当前任务的栈里，再从下一个任务的栈里恢复回来——就像游戏存档/读档。

```c
// FreeRTOSConfig.h 中的两行宏：
#define vPortSVCHandler    SVC_Handler    // 启动第一个任务 = FreeRTOS 的 SVC 函数
#define xPortPendSVHandler PendSV_Handler // 任务切换 = FreeRTOS 的 PendSV 函数
```

这两行告诉 Keil 的启动文件："别用你的空 SVC_Handler，用 FreeRTOS 的版本"。

---

## 六、FreeRTOSConfig.h 是什么

这是 FreeRTOS 的"设置菜单"。关键配置：

| 配置 | 我们的值 | 什么意思 |
|---|---|---|
| configTICK_RATE_HZ | 1000 | 调度器心跳 1ms 一次 |
| configMAX_PRIORITIES | 5 | 支持 5 级优先级 (0~4) |
| configTOTAL_HEAP_SIZE | 6KB | RTOS 可用内存（任务栈、队列等都从这里分） |
| configUSE_MUTEXES | 1 | 启用互斥量功能 |
| configUSE_RECURSIVE_MUTEXES | 1 | 启用递归互斥量（同一个任务可以多次锁） |

**堆大小 6KB 够用吗？**
- 6 个任务栈 ≈ 5KB
- 队列 + 互斥量结构体 ≈ 500B
- 内核自己 ≈ 300B
- 剩余约 200B 余量

STM32F103C8T6 总 SRAM 20KB，FreeRTOS 用了 6KB，剩余 14KB 给全局变量和 HAL 库——完全够。

---

## 七、今天踩的坑

### 坑1：configUSE_16_BIT_TICKS 没定义

FreeRTOS V10.x 新增的必选配置，忘了写。设为 0 = 32 位计数器，否则 49 天后 tick 溢出。

### 坑2：静态分配未关

开了 `configSUPPORT_STATIC_ALLOCATION=1` 但没提供对应的内存分配函数。FreeRTOS 想要我们告诉它"Idle 任务的栈放哪里"，但我们选择动态分配（`xTaskCreate` 自动从堆里拿），所以直接关掉。

### 坑3：调试钩子函数没实现

FreeRTOS 提供了"钩子"机制——发生特定事件时回调我们的函数。比如栈溢出时调用 `vApplicationStackOverflowHook`。但我们没写这些函数，编译器找不到就报错。解决方案：**全关**——这些都是调试用的，不影响功能。

---

## 八、新旧对比一览

| 维度 | 裸机 (v1.0) | FreeRTOS (v2.0) |
|---|---|---|
| 代码结构 | 1 个 while(1) 大循环 | 6 个独立任务 |
| 定时精度 | `if (g_sysTick - last > N)` 近似 | `vTaskDelayUntil()` 精确 |
| 任务切换 | 不支持（一个卡全卡） | 抢占式（高优先级立即可用） |
| 共享资源 | 单线程，不需要保护 | 3 个互斥量保护 I2C/数据/UART |
| 任务通信 | 全局变量 | 队列（先进先出，不丢事件） |
| 等待方式 | HAL_Delay 死等 | vTaskDelay 切到其他任务 |
| 实时性 | 差（DHT22 关中断期间全停） | 好（仅 SensorTask 关中断 2ms） |
| 专业性 | 课程设计级别 | 量产项目级别 |

---

## 九、如果想继续深入

1. **调优栈大小**：启用 `configCHECK_FOR_STACK_OVERFLOW=2` + 实现钩子，看实际栈使用量
2. **添加软件定时器**：用 FreeRTOS Timer 替代 vTaskDelayUntil（更省内存）
3. **中断与任务的配合**：传感器数据通过中断收集 → 信号量通知任务处理
4. **低功耗**：空闲任务钩子进入 Sleep 模式（电池供电场景）

---

> 一句话总结今天：**把 6 个"到点就干"的 if 判断，变成了 6 个独立的、被 RTOS 调度的、可以互相抢占的 while(1) 任务。**

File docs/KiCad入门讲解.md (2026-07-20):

# 🔧 KiCad 入门讲解 — 从零到第一个原理图

> 本教程基于 EnvMonitor 项目的实际经验编写，适合零基础新手。

---

## 1. KiCad 是什么？

KiCad 是一套**免费开源**的电路设计软件，用来画电路原理图和设计 PCB 电路板。

```
你的想法 → 画原理图（这个元件连那个元件） → 画PCB（铜线怎么走） → 导出文件发工厂 → 拿到实物板子
```

和立创EDA相比：KiCad 完全免费无限制、文件格式开放、全球开源社区支持。缺点是学习曲线稍陡。

---

## 2. KiCad 的界面组成

打开 KiCad 后会看到主界面，里面有几个核心工具：

| 图标 | 工具 | 干什么用 |
|---|---|---|
| 📝 | **原理图编辑器 (Eeschema)** | 画电路图，放元件，连线 |
| 🟢 | **PCB 编辑器 (Pcbnew)** | 设计电路板的铜线走线 |
| 📦 | **封装编辑器** | 编辑元件的物理尺寸（焊盘位置） |
| 🔣 | **符号编辑器** | 编辑元件的原理图符号（那个小方块图） |

> 新手只需要关注前两个：原理图编辑器 + PCB 编辑器。本讲解聚焦原理图编辑器。

---

## 3. 原理图编辑器的核心概念

### 3.1 元件（Symbol） — 电路里的"零件"

每个元件就是一个符号，比如电阻画成一个锯齿、电容画成两条平行线。元件上伸出小线头叫**引脚（Pin）**，连线就接在引脚上。

### 3.2 导线（Wire） — 电流的"路"

用导线把两个元件的引脚连起来，电流就能通过了。快捷键 `W`。

### 3.3 标签（Label） — "无线导线"

**这是 KiCad 中最重要也最容易出错的概念！**

```
如果你有两段导线离得很远，画线太乱，怎么办？
→ 在每段导线上各放一个同名标签，KiCad 会把它们当成同一条网络！
```

**坑点：标签必须放在导线上才能生效。** 放在空白处的标签是"死标签"——它创建了一条孤立的网，不和任何东西连通。你今天遇到的 KEY1/KEY2/KEY3 悬空问题就是这个原因。

### 3.4 网络（Net） — "同一条电路"

所有通过导线或同名标签连在一起的引脚，都属于**同一条网络**。比如 `KEY1` 网络包含 R7.pin2 + SW2.pin1 + C18.pin1 + H1.pin24，这四个点电压始终相等。

### 3.5 电源符号（Power Symbol） — 特殊的"全局标签"

`+3.3V`、`+5V`、`GND` 这些是特殊的全局标签。**只要原理图上出现同名的电源符号，它们自动连通，不需要画线。**

所以你可以到处放 GND 符号——它们全都连通。

### 3.6 No-Connect 标记（×号） — "这个脚故意不接"

有些元件的某些脚你真的不需要用。如果不加任何东西，ERC 会报"引脚未连接"。放一个 × 号就是告诉 KiCad："我知道这个脚空着，别报警。" 快捷键 `Q`。

### 3.7 PWR_FLAG — "电从这里来"

KiCad 需要知道每条电源轨的"电源从哪里输入"。PWR_FLAG 就是一个标记，告诉你："+5V 由核心板提供，不是漏画了电源芯片。"

---

## 4. ERC（电气规则检查）— 原理图的"编译"

**ERC = Electrical Rules Check = 检查你的电路有没有低级错误。**

就像写代码后的编译——程序"语法正确"不代表逻辑正确。ERC 能发现：
- 引脚忘了连线
- 标签悬空
- 电源网络没有电源来源
- 两个输出脚短路在一起

**但是：ERC 清零 ≠ 电路正确！** 你今天遇到的电容 No-Connect 问题就是例子——ERC 不报错，但消抖电容不接地就不工作。

---

## 5. 常用快捷键速查

| 快捷键 | 功能 |
|---|---|
| `W` | 画导线 |
| `L` | 放置标签 |
| `P` | 放置电源符号 |
| `Q` | 放置 No-Connect 标记 |
| `M` | 移动选中元件 |
| `G` | 拖动元件（导线跟着走） |
| `R` | 旋转元件 |
| `Delete` | 删除选中项 |
| `Ctrl+Z` | 撤销 |
| `Ctrl+S` | 保存 |

---

## 6. 一个完整的按键电路是怎么画出来的？

以 KEY1（PA4 按键）为例：

```
步骤1: 从库中拿出 SW2（按键开关）、R7（10k电阻）、C18（100nF电容）
步骤2: 摆放它们的位置，让 R7 在上面，SW2 在中间，C18 在下面
步骤3: 用 W 键画线：
       R7 上端 → +3.3V 电源符号
       R7 下端 + SW2 一脚 + C18 上端 → 三个连在同一个点
       SW2 另一脚 → GND
       C18 下端 → GND
步骤4: 在 R7+SW2+C18 的交汇导线上按 L，输入 "KEY1"，放置标签
步骤5: 在 H1 核心板插座旁边放一个 KEY1 标签 → 自动与上一步的 KEY1 合并
```

> 这就是标签的妙用——不用从按键画一根长线横跨整个原理图到核心板插座，放两个同名标签就完成了！

---

## 7. 新手常犯错误 Top 5

| 排名 | 错误 | 怎么发现 |
|---|---|---|
| 1 | 标签放在空白处 | ERC 报 "label_dangling" |
| 2 | 电阻电容在开关两边 | 手动画出电流路径检查 |
| 3 | 电容负极用 No-Connect 而不是 GND | ERC 不会报错，但电路不工作 |
| 4 | 开关夹在MCU和交汇点之间 | MCU 引脚悬空，读到随机电压 |
| 5 | 保存了原理图但没更新 ERC 导出 | 对着旧报告改了半天白改 |

---

## 8. 下一步：从原理图到 PCB

原理图完成后，下一步是 PCB 设计：

1. **给每个元件分配封装（Footprint）** — 告诉 KiCad 每个元件的实物尺寸
2. **导入到 PCB 编辑器** — 所有元件带着飞线（白色细线）出现在板子上
3. **摆放元件** — 像拼图一样把元件放在板上合适的位置
4. **布线** — 按照飞线的指引，画铜线连接各个引脚
5. **铺铜 + DRC 检查** — 在空白处铺上大面积的 GND 铜皮，运行设计规则检查
6. **导出 Gerber 文件** — 发给嘉立创打样

---

> 📚 相关文档：`原理图讲解.md` — 逐部分解释 EnvMonitor 的完整电路。

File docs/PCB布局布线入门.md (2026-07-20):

# 🟢 PCB 布局布线入门教学 — EnvMonitor 项目实战

> 接续 `KiCad入门讲解.md` 和 `原理图讲解.md`。打开 `hardware/pcb/EnvMonitor/EnvMonitor.kicad_pcb` 对着看。

---

## 第0章：PCB 是什么？

PCB（Printed Circuit Board）= 一块覆了铜的玻璃纤维板。铜被蚀刻成细细的"导线"（Track），把元件的引脚连接起来，替代面包板上杂乱的飞线。

```
面包板：  元件脚插在孔里 → 用杜邦线手动连接
PCB：     元件脚焊在焊盘上 → 铜箔蚀刻的细线自动连通
```

**你的 EnvMonitor PCB 是一块双面板（2层）：**
- **F.Cu（顶层）** — 正面铜皮，主要放元件和走线
- **B.Cu（底层）** — 背面铜皮，辅助走线 + 大面积 GND 铺铜

---

## 第1章：PCB 编辑器的核心概念

### 1.1 元件 = 封装（Footprint）= 实物在板上的"脚印"

| 原理图中叫 | PCB 中叫 | 就是 |
|---|---|---|
| 元件 (Symbol) | 封装 (Footprint) | 实物焊在板上的铜皮图案 |
| 电阻 R4 | `R_Axial_DIN0207_...` | 两个焊盘相距 2.54mm |
| 按键 SW2 | `SW_PUSH_6mm` | 4 个焊盘 6×6mm 排列 |

### 1.2 焊盘（Pad）= 元件脚焊上去的铜片

每个封装由若干个焊盘组成。焊盘有两种：
- **THT（通孔）焊盘**：中间有孔，元件脚穿过去在背面焊接
- **SMD（贴片）焊盘**：表面铜片，元件贴在表面焊接

你的板子全是 THT，意味着每个焊盘都有孔。

### 1.3 走线（Track）= 连接焊盘的铜线

在铜层上画一条线，电流就从 A 焊盘流到 B 焊盘。

### 1.4 飞线（Ratsnest）= "你应该这样连"

那些白色的细线就是飞线——它们不是真实的铜，只是提示："这两个焊盘是同一个网络，你应该画铜线连起来。"

> 飞线越少 = 布线越接近完成

### 1.5 过孔（Via）= 穿越板层的隧道

当一根线在顶层走到一半被挡住了，可以打一个过孔"钻"到底层继续走。

### 1.6 铺铜（Zone / Copper Pour）= 大面积铜皮

在板子的空白区域铺上一整块铜皮（通常是 GND 地），好处：
- 降低 GND 电阻，提供稳定参考地
- 散热更好
- 厂家蚀刻掉的铜更少（环保+省钱）

### 1.7 丝印（Silkscreen）= 板上的白字

标注元件编号（R4、C18）和方向标记（正极、pin1），方便焊接和调试。

---

## 第2章：常用操作速查

| 操作 | 快捷键 | 说明 |
|---|---|---|
| 移动元件 | `M` | 选中后移到新位置 |
| 旋转元件 | `R` | 每次旋转 90° |
| 拖动元件 | `G` | 元件移动但连好的线跟着走 |
| 画走线 | `X` | 开始布线，点击起点 → 点终点 |
| 打过孔 | `V` | 布线过程中按 V 切换到底层 |
| 删除走线 | `Delete` | 选中线后删除 |
| 切换层 | `Ctrl+Tab` 或点击面板 | 在 F.Cu / B.Cu 之间切换 |
| 铺铜 | `B` | 重新填充所有铺铜区域 |
| 测量距离 | `Ctrl+Shift+M` | 测量两点之间距离 |
| DRC 检查 | 顶部工具栏 DRC 图标 | 设计规则检查 |

---

## 第3章：布局的黄金法则

### 法则1：按信号流摆放

信号从左到右、从上到下流动。不要东一个元件西一个元件跳来跳去。

```
❌ 坏的布局：                  ✅ 好的布局：

[传感器]──20cm──[MCU]          [传感器]  [MCU]
    │                         (信号线短)
    └──15cm──[电阻]               │
                   │           [电阻]
                   └──10cm──[LED]  │
                                [LED]
```

### 法则2：核心板居中

H1/H2（Blue Pill 排母）放在板子中央偏上的位置。因为所有信号都从核心板发散出去，它应该像"枢纽站"一样在中心。

### 法则3：模块接口放板子边缘

J2(DHT22)、J3(OLED)、J4(HC-SR04)、J5(ESP8266) —— 这些是外部模块的插座，必须放在板边，方便插拔。

### 法则4：同类元件对齐

电阻和电阻排成一行、LED 和 LED 排成一行，间距一致。一是好看，二是方便焊接。

### 法则5：留出焊接空间

THT 元件之间至少留 **2-3mm** 间距。太挤的话烙铁头伸不进去，维修也困难。

### 法则6：先大后小

先放大的元件（排母 H1/H2、电解电容 C21/C22、模块插座 J2-J5），再放小的（电阻、LED、按键）。大元件决定板子布局的大框架。

---

## 第4章：布线的黄金法则

### 法则1：短、直、少过孔

线越短越好，拐弯越少越好。THT 板尽量全在底层走线，顶层留给元件。

### 法则2：电源线要粗

| 线宽 | 适合走什么 | 承载电流 |
|---|---|---|
| 0.3mm | 信号线（GPIO、I²C、UART） | ~0.5A |
| 0.5mm | 一般电源线 | ~1A |
| 0.8mm-1.0mm | **+5V 和 +3.3V 主干道** | ~2A |

> 你先用 0.3mm 走信号线，0.8mm 走电源主干线。GND 不用特意走线——最后铺铜一步解决。

### 法则3：走线不要锐角转弯

```
❌ 锐角：         ❌ 直角：        ✅ 45°角：
   \               │                ───┐
    \              │                   │
     \             └───                └──
```

KiCad 布线时默认就是 45° 角，保持默认即可。

### 法则4：先布信号线，再布电源线，最后 GND 铺铜

布线顺序：
1. 先走最短、最简单的信号线
2. 再走电源线（比信号线粗）
3. 最后大面积 GND 铺铜覆盖所有空白区域

### 法则5：GND 靠铺铜，不靠走线

不要去画 GND 走线！最后在整块板上画一个 GND 铺铜区域，所有 GND 焊盘自动连通。这样既省事效果又好。

---

## 第5章：⚠️ 新手最容易犯的错误

| 排名 | 错误 | 后果 | 怎么避免 |
|---|---|---|---|
| 1 | 忘记画板框 | 厂家不知道板子多大 | Edge.Cuts 层画个闭合矩形 |
| 2 | 走线和焊盘搭不上 | 电路断路 | 走线必须精确落在焊盘中心 |
| 3 | 顶层底层搞混 | 元件面走线被元件压住 | THT 走线全走 B.Cu（底层） |
| 4 | 线太细走电源 | 铜线发热或烧断 | +5V/+3.3V 用 0.8mm 以上 |
| 5 | 忘记铺铜 | GND 回路又长又细 | 布线完成后 B → 填充所有铺铜 |
| 6 | 铺铜后不跑 DRC | 短路或间距不够 | DRC → 全部通过才算完 |
| 7 | 元件摆到板框外面 | 厂家切掉了 | 所有元件必须在板框内 |

---

## 第6章：EnvMonitor 项目专属布局方案

### 6.1 板子尺寸

**建议：90mm × 65mm**（比之前说的 80×60 稍大，给手工焊接留余量）

> 嘉立创 10×10cm 以内打样 5 元/5片，你的板子完全在这个范围内。

### 6.2 推荐布局图

```
┌─────────────────────────────────────────────────────┐
│  90mm                                               │
│  ┌──────────────────────────────────────────────┐   │
│  │  J3(OLED+BH1750)    J2(DHT22)                │   │
│  │  4P排母上边           4P排母右边              │   │
│  │                                              │   │
│  │  ┌─────────┐   ┌─────────┐                   │   │
│  │  │ H1 左排母│   │ H2 右排母│   ← Blue Pill    │   │
│  │  │ 2x20P   │   │ 2x20P   │     核心板插座     │   │
│  │  └─────────┘   └─────────┘                   │   │
│  │                                              │   │
│  │  R4 R5 R6   ← I²C+DHT22 上拉电阻             │   │
│  │                                              │   │
│  │  SW2  SW3  SW4    ← 三个按键                  │   │
│  │  R7   R8   R9     ← 按键上拉电阻              │   │
│  │  C18  C19  C20    ← 消抖电容                  │   │
│  │                                              │   │
│  │  D2(红)  D3(黄)  D4(绿)  ← LED指示灯         │   │
│  │  R10     R11     R12     ← LED限流电阻        │65mm
│  │                                              │   │
│  │  J5(ESP8266)  C21  C22    ← WiFi+电源滤波    │   │
│  │  2x4P排母    100uF 100uF                     │   │
│  │                                              │   │
│  │  Q1 R13 R14 D5 LS1        ← 蜂鸣器驱动       │   │
│  │                                              │   │
│  │  J4(HC-SR04)              ← 超声波模块        │   │
│  │  4P排母右侧                                  │   │
│  └──────────────────────────────────────────────┘   │
└─────────────────────────────────────────────────────┘
```

### 6.3 各区域详解

**区域A — 核心板（板子中上部）：**
- H1、H2 两个 2x20P 排母平行放置，间距与 Blue Pill 核心板的排针间距一致
- Blue Pill 标准排针间距为 **22.86mm（900mil）**，这个数据必须在布局时精确设置
- 核心板 USB 口朝上（板边缘方向），方便插 USB 线

**区域B — I²C 上拉电阻（核心板旁边）：**
- R4(4.7k)、R5(4.7k)、R6(4.7k) 三个电阻紧挨 H1/H2 的对应引脚
- R4 靠近 PB6(SCL)，R5 靠近 PB7(SDA)，R6 靠近 PA0(DHT22)

**区域C — 按键区（板子中下部）：**
- SW2、SW3、SW4 三个按键水平排成一行，间距 **10mm**（手指好按）
- 每个按键上方放对应的上拉电阻（R7/R8/R9）
- 每个按键旁边紧贴消抖电容（C18/C19/C20）
- 从右到左排列：KEY1(SW2)、KEY2(SW3)、KEY3(SW4)

**区域D — LED 指示灯（按键下方）：**
- D2(红)、D3(黄)、D4(绿) 水平排成一行，间距 **5mm**
- 每个 LED 旁边放限流电阻（R10/R11/R12）
- LED 朝向板边，方便从外壳窗口看到

**区域E — 蜂鸣器驱动（板子右下角）：**
- Q1(S8050)、R13(1k)、R14(10k)、D5(1N4148)、LS1(蜂鸣器)
- 这些元件紧密排列在一起，因为它们是同一个功能电路

**区域F — 模块接口（板子边缘）：**
- J2(DHT22)、J3(OLED+BH1750) 放上边缘
- J4(HC-SR04) 放右边
- J5(ESP8266) 放下边
- 所有模块接口的开口方向朝板外

**区域G — 电源滤波（任意空位）：**
- C21(100µF/16V) 靠近 +5V 来源处
- C22(100µF/10V) 靠近 +3.3V 来源处

---

## 第7章：布线的具体参数

### 7.1 设计规则设置

在 KiCad PCB 编辑器中：**File → Board Setup → Design Rules → Constraints**

| 规则 | 推荐值 | 说明 |
|---|---|---|
| 最小线宽 | 0.3mm | 信号线默认宽度 |
| 最小间距 | 0.2mm | 铜线之间最小距离 |
| 最小过孔外径 | 0.8mm | 过孔的铜环外径 |
| 最小过孔钻孔 | 0.4mm | 过孔中间的孔 |

### 7.2 网络分类建议

在 **Board Setup → Net Classes** 中添加两个网络类：

| 网络类 | 线宽 | 包含哪些网络 |
|---|---|---|
| Power | 0.8mm | +5V, +3.3V |
| Default | 0.3mm | 所有信号（KEY1, I2C_SCL, LED_R 等） |

> GND 不需要出现在这里——它靠铺铜解决。

### 7.3 布线流程

```
步骤1: 关键信号线先走（I²C SCL/SDA, DHT22 DATA, HC-SR04 TRIG/ECHO, UART TX/RX）
         → 这些线要短，远离干扰源
   
步骤2: 一般信号线（LED, 按键, 蜂鸣器, ESP 控制脚）
         → 优先级较低，稍微绕一下没关系
   
步骤3: 电源线（+5V 和 +3.3V 用 0.8mm 粗线）
         → 从核心板供电引脚出发，依次经过各个需要供电的元件
   
步骤4: 铺地铜（在 B.Cu 层画一个覆盖全板的 GND zone）
         → 所有 GND 焊盘自动连接到大面积铜皮
         → F.Cu 层也铺 GND，两层之间打过孔连接
   
步骤5: 跑 DRC → 修正所有报错
```

---

## 第8章：DRC 检查清单

布线完成后，运行 DRC（设计规则检查），确保以下项目全部通过：

- [ ] **Unconnected items = 0** — 没有未连接的飞线
- [ ] **Clearance violations = 0** — 没有铜皮短路
- [ ] **Track width violations = 0** — 线宽符合规则
- [ ] **Board outline closed** — 板框是闭合图形
- [ ] **Copper edge clearance OK** — 铜皮不超出板框
- [ ] **Silkscreen not on pads** — 丝印文字没盖在焊盘上

---

## 第9章：输出 Gerber 文件（给工厂的文件）

### 9.1 导出步骤

PCB 编辑器中：**File → Fabrication Outputs → Gerbers**

| 要勾选的层 | 对应的文件 |
|---|---|
| F.Cu | 顶层铜皮 |
| B.Cu | 底层铜皮 |
| F.Silkscreen | 顶层丝印（白字） |
| B.Silkscreen | 底层丝印 |
| F.Mask | 顶层阻焊 |
| B.Mask | 底层阻焊 |
| Edge.Cuts | 板框 |

### 9.2 导出钻孔文件

**File → Fabrication Outputs → Drill Files**

### 9.3 发送给嘉立创

把 Gerber 文件夹打包成 `.zip`，上传到 https://jlcpcb.com 下单。

参数选择：
- 层数：2 层
- 板厚：1.6mm
- 铜厚：1oz
- 颜色：绿色（最便宜）
- 数量：5 片

---

## 第10章：快速参考卡片

```
╔══════════════════════════════════════════════╗
║         PCB 布局 Wiring 速查卡               ║
╠══════════════════════════════════════════════╣
║  M  = 移动元件     R  = 旋转 90°            ║
║  X  = 开始走线     V  = 布线中打过孔        ║
║  B  = 重新铺铜     Q  = 切换单位 mm/mil     ║
║  Delete = 删除走线                          ║
╠══════════════════════════════════════════════╣
║  信号线 = 0.3mm      电源线 = 0.8mm         ║
║  间距 ≥ 0.2mm       过孔 = 0.8/0.4mm       ║
║  GND靠铺铜  不走线                          ║
╠══════════════════════════════════════════════╣
║  先信号 → 再电源 → GND铺铜 → DRC            ║
║  短直少过孔  │  45°不走直角                 ║
║  元件不超出板框  │  留有焊接空间             ║
╚══════════════════════════════════════════════╝
```

---

> 📚 相关文档：
> - `KiCad入门讲解.md` — 软件基本操作
> - `原理图讲解.md` — 每一部分电路怎么工作的
> - `接线手册.md` — 原理图逐组接线指南

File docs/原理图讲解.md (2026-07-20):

# 📐 EnvMonitor 原理图讲解 — 逐电路分析

> 配合 `KiCad入门讲解.md` 阅读。打开 `hardware/pcb/EnvMonitor/EnvMonitor.kicad_sch` 对着看。

---

## 整体架构一览

```
                        STM32F103C8T6 核心板
                        (Blue Pill, 插在 H1+H2 排母上)
                                  │
        ┌─────────┬────────┬──────┼──────┬─────────┬─────────┐
        │         │        │      │      │         │         │
      DHT22     OLED    BH1750  HC-SR04  ESP8266   按键×3   LED×3+蜂鸣器
      (J2)      (J3)    (J3共享) (J4)   (J5)     (SW2-4)  (D2-4,LS1)
        │         │        │      │      │         │         │
      1-Wire     I²C      I²C    GPIO   UART     GPIO      GPIO
      (PA0)     (PB6/7)  (同总线) (PB0/1)(PA9/10) (PA4-6)  (PB12-15)
```

**核心设计思路：** STM32 核心板负责"大脑"，PCB 上的外围电路负责"接口"——把所有传感器、按键、显示器的引脚引到核心板的对应 GPIO 上。

---

## 第1部分：电源电路

```
原理图中的元件: C21(100µF), C22(100µF), 多个 +5V/+3.3V/GND 标签
```

### 电从哪里来？

- Blue Pill 核心板通过 USB 口取 5V 电
- 核心板上的 AMS1117-3.3V 把 5V 稳定成 3.3V 给 STM32 芯片
- PCB 通过排母 H1/H2 从核心板取 +5V 和 +3.3V

### 为什么额外加 C21 和 C22？

```
USB 5V ──┬── C21(100µF) ── GND     ← 滤掉 USB 电源的纹波
          │
          └── 给 HC-SR04 和蜂鸣器供电（它们需要 5V）

核心板 3.3V ──┬── C22(100µF) ── GND  ← 滤掉 3.3V 的纹波
               │
               └── 给其他所有 3.3V 元件供电
```

**大电容 = "蓄水池"**：当某个元件突然需要大电流时（比如 ESP8266 发射 WiFi），电容能瞬间提供电流，防止电压跌落。

### 电源网络统计

| 电源轨 | 电压 | 给谁供电 | 引脚数 |
|---|---|---|---|
| +5V | 5V | HC-SR04(J4)、蜂鸣器(LS1)、1N4148续流(D5) | 8 |
| +3.3V | 3.3V | 所有上拉电阻、DHT22、OLED、BH1750、ESP8266 | 17 |
| GND | 0V | 全部元件的地 | 37 |

---

## 第2部分：I²C 总线上拉

```
原理图中的元件: R4(4.7k), R5(4.7k), J3(OLED+BH1750 模块接口)
涉及信号: PB6_SCL, PB7_SDA
```

### I²C 为什么需要上拉电阻？

I²C 总线（SCL 时钟线 + SDA 数据线）是一种**开漏输出**接口。设备只能把线路"拉到 GND"（输出低电平），不能主动输出高电平。

```
没有上拉电阻:                   有上拉电阻:
                                 +3.3V
                                   │
3.3V? ← ─ ─ ─ ─ → 悬空!        R4/R5 (4.7k)
                                   │
SCL/SDA 线 ─── 设备拉低=0V       SCL/SDA ─── 设备拉低=0V，不拉=3.3V
```

> **一句话：R4/R5 保证 I²C 线路在不被拉低时保持在 3.3V（高电平）。**

### J3 模块：OLED + BH1750 共用 I²C

```
J3 是 4Pin 排母，插上 OLED 模块或 BH1750 模块：

J3.pin1 ── +3.3V        ← 供电
J3.pin2 ── PB6 (SCL)    ← 时钟线，通过 R4(4.7kΩ) 上拉到 +3.3V
J3.pin3 ── PB7 (SDA)    ← 数据线，通过 R5(4.7kΩ) 上拉到 +3.3V
J3.pin4 ── GND          ← 地
```

OLED 地址 = 0x3C（7位），BH1750 地址 = 0x23（7位）。地址不同，同一条 I²C 总线不会冲突。

---

## 第3部分：DHT22 温湿度传感器

```
原理图中的元件: R6(4.7k), J2(DHT22 模块接口)
涉及信号: PA0_DHT22
```

### DHT22 的 1-Wire 单总线

DHT22 只用一根数据线就能双向通信——STM32 先发开始信号，DHT22 回复 40bit 数据（湿度16bit + 温度16bit + 校验8bit）。

```
J2 是 4Pin 排母：

J2.pin1 ── +3.3V        ← 供电
J2.pin2 ── PA0(DATA)    ← 数据线，通过 R6(4.7kΩ) 上拉到 +3.3V
J2.pin3 ── NC (不接)    ← 空脚，加 No-Connect 标记
J2.pin4 ── GND          ← 地
```

R6 的作用同样是上拉——保证数据线空闲时保持 3.3V。4.7kΩ 是 DHT22 数据手册推荐的标准值。

---

## 第4部分：按键电路（本章的重点和难点！）

```
原理图中的元件: SW2/SW3/SW4, R7/R8/R9(10kΩ), C18/C19/C20(100nF)
涉及信号: PA4_KEY1, PA5_KEY2, PA6_KEY3
```

### 按键电路拓扑

以 KEY1 为例，画出电流走向：

```
         +3.3V
           │
        R7 (10kΩ 上拉电阻)
           │
           ├──── [KEY1标签] ────→ H1.pin24 (PA4) → STM32 读取电压
           │
        SW2.pin1 (按键一端)
           ║  按键
        SW2.pin2 (按键另一端)
           │
          GND
           │
        C18 (100nF 消抖电容)
           │
          GND
```

### 这个电路怎么工作？

**按键没按下时：**
- SW2 断开，电流路径：+3.3V → R7 → PA4
- PA4 读到 3.3V = 高电平 = 逻辑 "1"
- C18 通过 R7 充电到 3.3V

**按键按下时：**
- SW2 闭合，电流路径：+3.3V → R7 → SW2 → GND
- PA4 被 SW2 拉到 GND，读到 0V = 低电平 = 逻辑 "0"
- C18 通过 SW2 快速放电

**C18 (100nF) 的作用：**
按键按下/松开的瞬间，金属触点会快速弹跳（机械抖动），产生一串杂乱的脉冲。C18 像一个"小蓄水池"，让电压不能突变，把这些尖刺滤平。配合软件 30ms 延时消抖，达到双重保险。

### ⚠️ 今天踩的坑：开关方向反了！

**错误接法（开关夹在 MCU 和电路之间）：**
```
+3.3V → R → C → SW.pin1 ─║─ SW.pin2 → MCU(PA4)
```
不按时：PA4 悬空（读到随机值）← 绝对错误！
按下时：PA4 读到 3.3V ← 但这也没用，因为不到 0V

**正确接法（MCU 挂在交汇点上，开关控制是否接地）：**
```
+3.3V → R → [R + C + SW.pin1 + MCU] 交汇点
                    │
                 SW.pin2 → GND
```
不按时：PA4 = 3.3V（高）
按下时：PA4 = 0V（低）← 正确！

---

## 第5部分：LED 指示灯

```
原理图中的元件: D2(红LED), D3(黄LED), D4(绿LED), R10-R12(330Ω)
涉及信号: PB12_LEDR, PB13_LEDY, PB14_LEDG
```

### 为什么 LED 要串电阻？

LED 是电流型器件——电压超过导通电压（红色约1.8V）后，电流会急剧增大烧毁 LED。串一个电阻限制电流：

```
PB12 → R10(330Ω) → D2(红LED) → GND

电流计算: I = (3.3V - 1.8V) / 330Ω ≈ 4.5mA  ← 安全范围
```

| 颜色 | GPIO | 电阻 | 含义 |
|---|---|---|---|
| 🔴 红 | PB12 | R10(330Ω) | 高温报警 |
| 🟡 黄 | PB13 | R11(330Ω) | 湿度异常 |
| 🟢 绿 | PB14 | R12(330Ω) | 人体靠近检测 |

---

## 第6部分：蜂鸣器驱动电路

```
原理图中的元件: Q1(S8050), R13(1kΩ), R14(10kΩ), D5(1N4148), LS1(蜂鸣器)
涉及信号: PB15_BUZZ
```

### 为什么需要三极管驱动？

STM32 的 GPIO 引脚最大输出电流约 8mA，而蜂鸣器可能需要 30-50mA。三极管就像一个"电子开关"：

```
PB15 (GPIO) ── R13(1kΩ) ── Q1 的 B(基极)
                               │
                        小电流控制 ↓  大电流通过
                               │
                     +5V ── 蜂鸣器 ── Q1的C(集电极) ── Q1的E(发射极) ── GND
```

- GPIO 输出 3.3V → Q1 导通 → 蜂鸣器电流从 +5V 流过 → 蜂鸣器响
- GPIO 输出 0V → Q1 截止 → 蜂鸣器不响

### R13/R14/D5 各自的作用

| 元件 | 作用 |
|---|---|
| R13(1kΩ) | 限制 PB15 → Q1 基极的电流，保护 GPIO 口 |
| R14(10kΩ) | 基极下拉电阻，GPIO 未初始化时保证 Q1 关断（防止一上电乱叫） |
| D5(1N4148) | **续流二极管**——蜂鸣器是感性负载，断开瞬间会产生反向高压，D5 把这个高压短路掉保护 Q1 |

---

## 第7部分：HC-SR04 超声波测距

```
原理图中的元件: J4(HC-SR04 模块接口)
涉及信号: PB0_HC_TRIG, PB1_HC_ECHO
```

HC-SR04 是 4Pin 模块，用 +5V 供电：

```
J4.pin1 ── +5V           ← 供电 (注意是5V不是3.3V！)
J4.pin2 ── PB0 (TRIG)    ← STM32 发出 10µs 高脉冲触发测量
J4.pin3 ── PB1 (ECHO)    ← HC-SR04 返回高电平，脉宽 = 距离
J4.pin4 ── GND
```

**PB1 需要定时器输入捕获功能（TIM3_CH4）**，这是 CubeMX 中特别配置的，不能用普通 GPIO。

---

## 第8部分：ESP8266 WiFi 模块

```
原理图中的元件: J5(ESP8266-01S 模块接口)
涉及信号: PA9_TX, PA10_RX, ESP_RST, ESP_GPIO0
```

ESP8266-01S 是 2x4Pin（8脚）模块：

| 脚号 | 信号 | 连接 | 说明 |
|---|---|---|---|
| 1 | VCC | +3.3V | ⚠️ 必须 3.3V，不能接 5V！ |
| 2 | GPIO2 | NC | 内部已上拉，不接 |
| 3 | CH_PD/EN | +3.3V | 使能脚，必须拉高模块才工作 |
| 4 | RST | H2.p9 | 复位脚 |
| 5 | TX | PA10 (USART1_RX) | ESP 发送 → STM32 接收 |
| 6 | RX | PA9 (USART1_TX) | STM32 发送 → ESP 接收 |
| 7 | GPIO0 | NC | 烧录固件时才用到 |
| 8 | GND | GND | 地 |

> TX/RX 是交叉连接的：A 的 TX 接 B 的 RX，A 的 RX 接 B 的 TX。很多人第一次都会接反！

---

## 第9部分：核心板插座

```
原理图中的元件: H1(左排母 2x20P), H2(右排母 2x20P)
```

Blue Pill 核心板通过 H1+H2 插入 PCB。原理图只需要用标签把信号引到对应的连接器引脚上：

| 信号标签 | H 引脚 | Blue Pill 物理位置 |
|---|---|---|
| PA0_DHT22 | H1.p32 | 左排母 PA0 |
| PA4_KEY1 | H1.p24 | 左排母 PA4 |
| PA5_KEY2 | H1.p22 | 左排母 PA5 |
| PA6_KEY3 | H1.p20 | 左排母 PA6 |
| PB0_HC_TRIG | H1.p16 | 左排母 PB0 |
| PB1_HC_ECHO | H1.p14 | 左排母 PB1 |
| ESP_GPIO0 | H1.p30 | 左排母 PA1 |
| +3.3V | H1.p6 | 左排母 3.3V |
| GND | H1.p2, p4 | 左排母 GND |
| PB12_LEDR | H2.p1 | 右排母 PB12 |
| PB13_LEDY | H2.p3 | 右排母 PB13 |
| PB14_LEDG | H2.p5 | 右排母 PB14 |
| PB15_BUZZ | H2.p7 | 右排母 PB15 |
| ESP_RST | H2.p9 | 右排母 PA8 |
| PA9_TX | H2.p11 | 右排母 PA9 |
| PA10_RX | H2.p13 | 右排母 PA10 |
| PB6_SCL | H2.p27 | 右排母 PB6 |
| PB7_SDA | H2.p29 | 右排母 PB7 |
| +5V | H2.p35 | 右排母 5V |
| GND | H2.p37 | 右排母 GND |
| +3.3V | H2.p39 | 右排母 3.3V |

> ⚠️ H1/H2 的引脚编号（1-40）是 KiCad 连接器的内部编号，和 Blue Pill 丝印上的编号不完全对应。PCB 布局时需要逐个确认物理位置。

---

## 完整的信号对照速查表

| STM32 引脚 | 信号标签 | 功能 | 外设类型 |
|---|---|---|---|
| PA0 | DHT22_DATA | DHT22 温湿度 | 1-Wire 单总线 |
| PA4 | KEY1 | 按键1（页面切换） | GPIO 输入 |
| PA5 | KEY2 | 按键2（确认） | GPIO 输入 |
| PA6 | KEY3 | 按键3（返回） | GPIO 输入 |
| PA9 | ESP_TX | USART1 发送 → ESP | UART |
| PA10 | ESP_RX | USART1 接收 ← ESP | UART |
| PB0 | HC_TRIG | HC-SR04 触发 | GPIO 输出 |
| PB1 | HC_ECHO | HC-SR04 回响 | 定时器捕获 |
| PB6 | I2C_SCL | I²C 时钟 | I²C1 |
| PB7 | I2C_SDA | I²C 数据 | I²C1 |
| PB12 | LED_R | 红色LED | GPIO 输出 |
| PB13 | LED_Y | 黄色LED | GPIO 输出 |
| PB14 | LED_G | 绿色LED | GPIO 输出 |
| PB15 | BUZZ | 蜂鸣器 | GPIO 输出 |

---

## 原理图检查清单

在进入 PCB 设计前，确认以下每一条：

- [ ] 每个元件的 Value 正确（电阻阻值、电容容值）
- [ ] 每条信号标签都放在导线上
- [ ] 所有电容负极接地（不是 No-Connect）
- [ ] 大电容 C21/C22 正极接电源、负极接地
- [ ] ESP8266 供电是 +3.3V 不是 +5V
- [ ] HC-SR04 供电是 +5V
- [ ] I²C 有上拉电阻 R4/R5 (4.7k)
- [ ] DHT22 有上拉电阻 R6 (4.7k)
- [ ] 按键电路：R+C+SW+MCU 在同一交汇点，SW 另一端接地
- [ ] ERC 错误全部分析过（不是简单清零）
- [ ] 每个元件都分配了正确的封装 (Footprint)

---

> 📚 相关文档：`KiCad入门讲解.md` — KiCad 软件基本操作和概念。

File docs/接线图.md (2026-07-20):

# 🔌 引脚分配表

## 总览

```
STM32F103C8T6       外设                 说明
────────────────────────────────────────────────
PA0                 DHT22 DATA          1-Wire 单总线
PA1                 (预留 ADC)           可用于电池电压检测
PA9  (USART1_TX)    ESP8266 RX          UART 发送→WiFi接收
PA10 (USART1_RX)    ESP8266 TX          UART 接收←WiFi发送
PA4                 KEY1                按键1（页面切换）
PA5                 KEY2                按键2（确认）
PA6                 KEY3                按键3（返回）
PB0                 HC-SR04 Trig        超声波触发信号
PB1                 HC-SR04 Echo        超声波回响捕获（TIM3_CH4）
PB6  (I2C1_SCL)     OLED SCL + BH1750 SCL  共用I2C总线时钟
PB7  (I2C1_SDA)     OLED SDA + BH1750 SDA  共用I2C总线数据
PB12                LED_RED             红色LED（高温报警）
PB13                LED_YELLOW          黄色LED（湿度低）
PB14                LED_GREEN           绿色LED（靠近检测）
PB15                BUZZER              有源蜂鸣器（PWM驱动）
PA2  (USART2_TX)    (预留) 调试串口
PA3  (USART2_RX)    (预留) 调试串口
PA13 (SWDIO)        ST-Link 调试口
PA14 (SWCLK)        ST-Link 调试口
```

## I2C 总线设备地址
| 设备 | 7位地址 | 8位地址 |
|---|---|---|
| OLED SSD1306 | 0x3C | 0x78 |
| BH1750 | 0x23 | 0x46 |

## 系统时钟配置
- 主频：72MHz (HSE 8MHz × PLL)
- APB1：36MHz
- APB2：72MHz
- SysTick：1ms (FreeRTOS 心跳)

## 电源
- STM32 核心供电：3.3V (AMS1117 稳压)
- HC-SR04 供电：5V (USB 直接取电)
- 蜂鸣器供电：5V

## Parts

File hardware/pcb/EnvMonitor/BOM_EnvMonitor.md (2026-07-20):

# 📋 EnvMonitor BOM 物料清单

> 板名：EnvMonitor | 主控：STM32F103C8T6 | 尺寸：80×60mm | 2层

---

## 一、PCB 焊接件（27 个）

### 🔌 连接器

| 位号 | 数量 | 规格 | 单价 | 小计 |
|---|---|---|---|---|
| H1, H2 | 2 | 1×20P 排母 (1×40P 掰断) | 0.42 | 0.42 |
| J2/J3/J4/LS1/J5 | 5 | 1×4P / 2×4P / 1×3P 排针 (1×40P 截取) | 0.18 | 0.18 |

### ⚡ 电阻 — 1/4W 金属膜

| 位号 | 数量 | 阻值 | 用途 | 来源 |
|---|---|---|---|---|
| R10~R12 | 3 | 330Ω | LED 限流 | 电阻包 |
| R4~R6 | 3 | 4.7kΩ | I2C 上拉 | 电阻包 |
| R7~R9 | 3 | 10kΩ | 按键上拉 | 电阻包 |
| | | | **电阻包 (30种×10, 1/4W)** | **3.20** |

### 🔵 电容

| 位号 | 数量 | 参数 | 用途 | 来源 |
|---|---|---|---|---|
| C18~C20 | 3 | 100nF (104) 瓷片 | 按键消抖 | 瓷片电容包 |
| C22 | 1 | 100µF / 10V 电解 | 3.3V 滤波 | 电解电容包 |
| C21 | 1 | 100µF / 16V 电解 | 5V 滤波 | 电解电容包 |
| | | | **瓷片电容 104 (100个)** | **1.95** |
| | | | **电解电容 100µF/10V (50个)** | **2.64** |
| | | | **电解电容 100µF/16V (50个)** | **2.64** |

### 💡 LED — 3mm 直插

| 位号 | 数量 | 颜色 | 用途 |
|---|---|---|---|
| D2 | 1 | 红色 | 高温报警 |
| D3 | 1 | 黄色 | 湿度报警 |
| D4 | 1 | 绿色 | 靠近检测 |
| | | | **LED 红黄绿 各10只** | **1.50** |

### 🔘 按键

| 位号 | 数量 | 规格 | 用途 |
|---|---|---|---|
| SW2~SW4 | 3 | 6×6×4.3mm 轻触开关 | KEY1/KEY2/KEY3 |
| | | | **轻触开关 6×6 (20个)** | **0.66** |

---

## 二、外接模块（7 个）

| 模块 | 数量 | 接口 | 单价 |
|---|---|---|---|
| STM32F103C8T6 Blue Pill 核心板 | 1 | 2×20P 排针 | 12.00 (含 ST-Link) |
| DHT22 / AM2302 温湿度传感器 | 1 | 4Pin | 5.28 |
| GY-302 光照传感器 (BH1750) | 1 | I²C | 6.05 |
| OLED 0.96" SSD1306 黄蓝双色 | 1 | I²C 4Pin | 10.86 |
| HC-SR04 超声波测距模块 | 1 | 4Pin | 4.95 |
| ESP8266-01S WiFi 模块 (安信可) | 1 | 2×4Pin | 10.45 |
| 5V 有源蜂鸣器模块 | 1 | 3Pin | 1.76 |

---

## 三、工具

| 物品 | 单价 | 用途 |
|---|---|---|
| USB 转 TTL (CH340) | 5.28 | ESP8266 调试 / AT 烧录 |
| Micro USB 线 | 自备 | Blue Pill 供电 |

---

## 四、PCB 打样

| 项目 | 单价 |
|---|---|
| 嘉立创 双面板 80×60mm 5张 | **20.00** |

---

## 五、成本汇总

| 类别 | 金额 |
|---|---|
| PCB 焊接件 (分立元件) | 12.79 |
| PCB 焊接件 (连接器) | 0.60 |
| 外接模块 (7个) | 51.35 |
| 工具 | 5.28 |
| PCB 打样 | 20.00 |
| **合计** | **90.02 元** |

> 📝 以上为按最终方案计算的实际购买价格。分立元件按整包购买价计算（无法零买），实际用量远小于购买量。
>
> ⚠️ 采购方案变更记录：蜂鸣器从 2 脚裸头+NPN驱动 → 3 脚模块直连；由此弃用 S8050 (2.86元) / 1N4148 (2.86元) / AMS1117 (0.55元)，实际总花费约 96 元。

---

> 📝 **BOM 生成时间**: 2026-07-20 | **价格来源**: 立创商城 2026-07 实际购买

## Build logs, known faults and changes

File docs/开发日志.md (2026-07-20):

# 🛠️ 开发日志 — 智能环境监测与物联网控制站

> 记录项目的关键设计决策、踩坑经验和解决思路。
> 适合发到 GitHub 做项目文档，也方便复盘回顾。

---

## 📅 2026-07-15 — 项目启动 + 方案设计

### Q: 为什么选这个方案？

- STM32F103C8T6 是最经典的学习平台，有大量社区资源，出问题容易查
- 覆盖三种总线（I2C、1-Wire、UART），学一个项目打通嵌入式通信基础
- 有显示、有输入、有声光、有无线通信——组件齐全，属于完整 IoT 终端

### Q: 为什么 OLED 和 BH1750 用同一组 I2C？

- 两者都是 I2C 器件且地址不同（OLED=0x78, BH1750=0x46），不会冲突
- 共用 PB6/PB7 省下 GPIO 给后续扩展
- 这是工程上常见做法：一条总线挂多个从设备

### Q: 为什么先面包板再 PCB？

- 面包板阶段能随便改接线，发现设计错了不受惩罚
- PCB 打样一块板子 5 元但如果改一版就是 5+5，面包板改线零成本
- 功能全部调通再画 PCB，保证一次成功

### Q: 为什么用有源蜂鸣器而不是无源蜂鸣器？

- 有源蜂鸣器通电即响，不用生成 PWM 频率信号
- 报警场景只需要"滴滴滴"，不需要播放音乐旋律
- 一个 GPIO 拉高就响，代码量和调试难度都更低

### Q: 为什么用 ESP8266 AT 指令而不是直接编程 ESP8266？

- STM32 做主控更灵活：传感器数据先在本机处理，要传什么再发
- AT 指令方式调试方便：用串口助手就能看到通信过程
- ESP8266 出厂自带 AT 固件，不用刷 SDK

### 📌 引脚分配原则

- **PA9/PA10** → USART1（ESP8266 通信），这是 STM32 固定分配
- **PA13/PA14** → 保留 SWD 调试接口（烧录程序、断点调试）
- **PB6/PB7** → I2C1（硬件 I2C），比软件模拟 I2C 更稳定
- **PA0** → DHT22 需要精确微秒时序
- **PB0/PB1** → HC-SR04 Echo 需要定时器输入捕获
- **PB12-PB15** → LED、蜂鸣器等普通 GPIO 外设

---

## 📅 2026-07-16（上） — 固件代码编写

### 💡 整体架构：为什么分三层？

```
Drivers/  → 硬件抽象层（"怎么读传感器"）
   ↓
App/      → 业务逻辑层（"数据怎么用"）
   ↓
Core/     → 调度层（"什么时候做什么"）
```

好处：改一个传感器不影响别的模块。比如想把 DHT22 换成 DHT11，只改 `Drivers/DHT22/` 内的代码，App 层完全不需要动。

### 💡 各驱动设计要点

**DHT22 — 为什么关中断？**
单总线时序要求微秒级精度。SysTick 中断恰好 1ms 一次，如果在读 40bit 数据时被中断打断，高电平计时就偏了，校验必错。`__disable_irq()` / `__enable_irq()` 包围整个读取过程，2ms 内完成，不影响其他任务。

**HC-SR04 — 输入捕获反转极性**
先捕获上升沿记录起始时间，立刻切到下降沿捕获结束时间。硬件定时器自动记录，不用软件轮询（会被中断干扰）。TIM3 时钟 1MHz（1us精度），`距离(cm) = 脉宽(us) / 58`。

**按键 — 状态机消抖**
每个按键 4 个状态：空闲 → 消抖等待(30ms) → 确认按下 → 长按(1s)。
30ms 过滤机械抖动，1s 触发长按，超过 1s 后每 200ms 产生 HOLD 连发事件。事件读后自动清除，不会重复触发。

**ESP8266 — 为什么用 HTTP GET 而不是 MQTT？**
Thingspeak 原生支持 HTTP GET 更新数据，不需要 MQTT broker。AT 指令模式：TCP连接 → HTTP请求 → 关闭TCP，链路清晰。后续升级 MQTT 只需改 `esp8266.c`，应用层接口不变。

**I2C 总线共用**
OLED(0x78) 和 BH1750(0x46) 地址不同，共用 PB6/PB7。HAL 的 I2C 函数是同步阻塞的，主循环里顺序调用不会冲突。上 FreeRTOS 后只需加一个互斥信号量保护。

**为什么选 Thingspeak？**
免费（每年 300 万条消息），有现成的图表和数据导出。自建服务器要花钱租云服务，不符合 100 元预算。注册：https://thingspeak.com → 创建 Channel(4个Field) → 填 API Key 到 `esp8266.h`。

---

## 📅 2026-07-16（下） — CubeMX 工程整合 + Keil 编译

### 💡 关键踩坑记录

#### Q1: 标准库 vs HAL 库，会不会有影响？

**不会。** 标准库学到的是寄存器思维，HAL 只是换了个函数名。初始化代码 CubeMX 生成，驱动逻辑完全自己写。标准库的 `GPIO_SetBits()` → HAL 的 `HAL_GPIO_WritePin()`，本质上操作同一个寄存器。HAL 是当前行业标准，简历和 GitHub 上更有说服力。

#### Q2: CubeMX 中 TIM3 的 Slave Mode 和 Trigger Source？

**都不选。** Slave Mode = Disabled，Trigger Source 保持灰色。HC-SR04 只需要 TIM3_CH4 做 Input Capture，不需要外部信号触发/复位/门控定时器。
- Prescaler = 72-1 = 71 → 1MHz = 1us 精度
- Period = 65535（最大计数）
- Channel4 = Input Capture direct mode

#### Q3: USART1 Mode 选什么？

**Asynchronous（异步模式）。** ESP8266 和 STM32 就是最普通的 TX+RX 两根线全双工串口，不需要同步时钟线，不需要硬件流控（RTS/CTS）。
- Baud Rate: 115200
- Word Length: 8 Bits
- Parity: None
- Stop Bits: 1

#### Q4: Clock Configuration 中 HSE 是黑的？

因为在 Pinout 页面没启用 HSE。**System Core → RCC → High Speed Clock → Crystal/Ceramic Resonator**，回到 Clock Configuration 就亮了。
- HSE(8MHz) → PLL Source Mux → PLL(×9) → SYSCLK(72MHz)
- AHB=72, APB2=72, APB1=36

#### Q5: Keil 编译 cannot open source input file "oled.h"？

头文件搜索路径没加。**Project → Options for Target → C/C++ → Include Paths → ...** → 添加 `..\Drivers\OLED` 等 9 个目录。`..\` 是从 MDK-ARM 目录向上一级到达 EnvMonitor 根目录。

#### Q6: 加了路径还是报 cannot open "oled.h"？（关键问题）

**根本原因：循环包含。**

```
main.h ──→ #include "oled.h"
               ↓
           oled.h ──→ #include "main.h"
                         ↓
                    头文件保护符(__MAIN_H)挡住
                         ↓
                    main.h 中后续的类型定义都不生效
                         ↓
                    编译器报错"找不到"
```

**解决方案：**
1. 所有驱动/应用的 `.h` 文件：`#include "main.h"` → `#include "stm32f1xx_hal.h"`
2. 所有 `.c` 文件：在 include 自己的 `.h` 之前先 `#include "main.h"`
3. `main.h` 中把所有宏定义和 typedef 移到 include 驱动头文件之前

**修复后的包含链：**
```
.c 文件 → #include "main.h" → 拿到所有类型定义
       → #include "自己.h" → 拿到函数声明
```

#### Q7: Undefined symbol SystemClock_Config？

替换 main.c 时把 CubeMX 生成的 `SystemClock_Config()` 函数体搞丢了。CubeMX 原版 main.c 底部有这个函数定义，替换后需要补回来。

---

## 🗺️ 当前阶段执行路线图

```
P0: 项目规划 + 器件采购     ✅ 2026-07-15
P1: GPIO (LED/按键/蜂鸣器)  ✅ 2026-07-16 代码就绪
P2: OLED 显示              ✅ 2026-07-16 代码就绪
P3: 传感器驱动 (DHT22/BH1750) ✅ 2026-07-16 代码就绪
P4: OLED 菜单              ✅ 2026-07-16 代码就绪
P5: HC-SR04 + 报警         ✅ 2026-07-16 代码就绪
P6: ESP8266 WiFi + 云      ✅ 2026-07-16 代码就绪
--- 代码与编译分界线 ---
P1-P6: CubeMX 工程整合      ✅ 2026-07-16 Keil 编译通过
P1-P6: 硬件烧录验证         ⏳ 等待器件到货
P7: FreeRTOS 重构           ✅ 2026-07-17 代码+编译均完成
P8: PCB 设计 + 打样         🔄 2026-07-17原理图完成，07-18导入PCB(未布局)
P9: GitHub 发布             ⬜ 待开始
```

### 经验总结：花在工程配置上的时间值不值？

**值。** HAL 库工程配置（CubeMX + Keil + 循环包含修复）是整个项目中最容易卡住的环节。今天踩的坑——循环包含、头文件路径、SystemClock_Config 丢失——都是 HAL 和 CubeMix 组合的经典问题。**搞通一次，以后所有 STM32 项目都能快速起步。**

### 后续注意事项

1. **每次 CubeMX 重新生成代码后**，Include Paths 会被重置，需要重新添加 Drivers 和 App 路径
2. **WiFi 账号密码** 在 `esp8266.h` 中修改，不要提交到 GitHub（用 .gitignore 或环境变量）
3. **Thingspeak API Key** 同理，属于私密信息
4. **GPIO 配置** 如被 CubeMX 覆盖，需重新手动修正（PA0开漏、按键上拉等）

---

## 📅 2026-07-17 — P7: FreeRTOS 任务重构

### 💡 为什么做 FreeRTOS 迁移？

裸机超级循环在简单项目是好选择，但项目有 6 个不同节奏的操作——5秒采样、1秒刷新、60秒上云、500ms报警、20ms按键、事件驱动的蜂鸣——全塞在一个 while(1) 里用时间戳区分，扩展性差。FreeRTOS 让每个功能独立运行，抢占式调度保证实时性。

### 💡 架构设计：3 层保护 + 2 条消息通道

**资源保护（互斥量）：**
- `I2C_Mutex` — OLED 和 BH1750 共享 I2C1 总线，同时访问会数据错乱
- `Data_Mutex` — g_sensorData 被 4 个任务读写，需要原子性保证
- `UART_Mutex` — ESP8266 独占 UART1，DisplayTask 手动重连和 CloudTask 自动上云可能冲突

**任务通信（队列）：**
- `ButtonQueue` — ButtonTask 扫描到事件 → DisplayTask 消费（解耦扫描和响应）
- `BuzzerQueue` — AlarmTask 发蜂鸣指令 → BuzzerTask 阻塞等待执行（蜂鸣节奏不被其他任务打断）

### 💡 6 个任务设计考量

| 任务 | 优先级 | 周期 | 关键决策 |
|---|---|---|---|
| SensorTask | 3 | 5s | DHT22 仍用 taskENTER_CRITICAL 关中断 ~2ms；BH1750 持 I2C 锁 |
| AlarmTask | 3 | 500ms | 高温优先级最高（continue 跳过其余）；→队列控制蜂鸣 |
| DisplayTask | 2 | 1s | 先消费按键队列再渲染；持 I2C/Data 双锁 |
| ButtonTask | 2 | 20ms | vTaskDelayUntil 精确周期；非阻塞队列发送 |
| BuzzerTask | 2 | 事件 | 阻塞在 xQueueReceive，无指令时零 CPU |
| CloudTask | 1 | 60s | 最低优先级（AT 指令阻塞 5-15s 不干扰 UI/采集） |

### 💡 SysTick 三分天下

SysTick_Handler 同时服务三个对象：
```c
HAL_IncTick();                            // HAL 库 (HAL_Delay 等)
g_sysTick++;                              // 我们自己的毫秒计数
xPortSysTickHandler();   // FreeRTOS tick (任务调度时钟)
```

关键细节：调度器启动前不调用 `xPortSysTickHandler()`，否则访问未初始化的内核结构会 HardFault。用 `xTaskGetSchedulerState() != taskSCHEDULER_NOT_STARTED` 判断。

### 💡 SVC/PendSV 为何移交给 FreeRTOS？

Cortex-M3 中：
- **SVC**（系统服务调用）：FreeRTOS 用它启动第一个任务（`vPortSVCHandler` 设置 MSP/PSP 后跳转）
- **PendSV**（可挂起系统调用）：FreeRTOS 用它做上下文切换（保存当前任务寄存器 → 恢复下一任务）

这两个中断必须由 FreeRTOS 控制。`FreeRTOSConfig.h` 中的宏 `#define vPortSVCHandler SVC_Handler` 把 FreeRTOS 函数映射到启动文件的向量表名，替代了原本的弱定义空函数。

### 💡 为什么不直接用 CubeMX 生成 FreeRTOS？

CubeMX 生成的 FreeRTOS 使用 CMSIS-RTOS v2 封装层（`osThreadNew` / `osMutexNew` 等），好处是跨 RTOS 可移植，代价是：
- 多一层封装调用开销
- 出错时调试更间接
- 学习到的 API 绑定在 CMSIS 生态

直接用 FreeRTOS 原生 API（`xTaskCreate` / `xSemaphoreCreateMutex`），社区资源丰富、面试更认可，且能深入理解 RTOS 原理。

### 💡 STM32CubeF1 自带 FreeRTOS 不用下载

STM32Cube_FW_F1_V1.8.7 固件包 `Middlewares/Third_Party/FreeRTOS/Source/` 已包含完整 FreeRTOS V10.3.1 源码。RVDS/ARM_CM3 移植层（port.c）天然兼容 Keil MDK 的 ARMCC 编译器。不用额外下载，直接从 `C:\Users\Monesy\STM32Cube\Repository\` 复制到工程即可。

### 💡 Keil 编译踩坑记录（FreeRTOS 特有）

**Q8: `#error Missing definition: configUSE_16_BIT_TICKS`**

FreeRTOS V10.x 新增的必选宏，V9.x 没有。必须设为 0（32位MCU用32位计数器）。我们漏写了，在 FreeRTOSConfig.h 补上即可。

**Q9: `configSUPPORT_STATIC_ALLOCATION` + `configSUPPORT_DYNAMIC_ALLOCATION` 必须定义**

V10.x 引入的静态/动态分配双模式。两个至少要有一个为 1（否则系统无法分配任何内存）。我们开了静态分配(=1)但没提供 `vApplicationGetIdleTaskMemory` 函数，导致链接报错。解决：关掉静态分配(=0)，只用动态分配(=1)。

**Q10: `Undefined symbol vApplicationMallocFailedHook` 等 4 个钩子函数**

FreeRTOS 的调试钩子（malloc失败、栈溢出、空闲任务内存、定时器任务内存）需要用户实现，但我们没写。这些钩子全是调试用途——关了不影响功能：
- `configUSE_MALLOC_FAILED_HOOK = 0`
- `configCHECK_FOR_STACK_OVERFLOW = 0`
- `configSUPPORT_STATIC_ALLOCATION = 0`（顺便解决了 Q9）

后续项目稳定后可以重新开启栈溢出检测（方法1/2）并补充钩子函数。

---

## 📅 2026-07-17（下）— P8: PCB 原理图设计

### 💡 为什么选方案B（全插件/模块化）？

最初考虑方案A（全贴片SMD），但在评估焊接难度后转向方案B：

- STM32F103C8T6 核心板单独购买（Blue Pill 约12元），自带晶振+AMS1117+USB+SWD，不重复画这些电路
- 核心板通过 2x20P 排母插在 PCB 上，方便更换
- 所有电阻/RED/三极管/二极管全用插件封装，新手也能手焊
- 模块（DHT22/OLED/BH1750/HC-SR04/ESP8266）通过排针排母连接，即插即用
- **理念：把复杂的焊接交给工厂（核心板），把简单的插件留给手工**

### 💡 为什么用 KiCad 而不是立创EDA？

- KiCad 开源免费，无商业限制，GitHub 上更受认可
- S-expression 文件格式透明，可以用 Python 脚本辅助生成
- 立创EDA绑定嘉立创生态，后续迁移成本高
- KiCad 10.0 版本已足够成熟，社区资源丰富

### 💡 元件选择原则

核心板上已有的元件不重复画（STM32芯片、晶振x2、AMS1117-3.3V、去耦电容x9、USB、SWD、复位电路、BOOT0电路、电源LED）。PCB 上只放额外需要的外围电路。

额外增加：
- C21 (100µF/16V) +5V 电解滤波
- C22 (100µF/10V) +3.3V 电解滤波
- 所有模块接口排针排母
- 所有用户交互元件（按键、LED、蜂鸣器）

### 💡 Python 脚本辅助生成原理图

编写了多个 Python 脚本用来自动生成 KiCad 原理图（`hardware/pcb/*.py`），核心思路：
- 从 KiCad 标准库中提取元件符号定义
- 用坐标定位方式摆放元件、画线、放标签
- 支持分7组独立生成和整体生成两种模式

**经验教训：** 脚本生成快但不够灵活，手动调整后脚本和原理图容易脱节。**以后建议：脚本做初始布局，手动精调，不要来回生成。**

### 💡 核心踩坑：KiCad 标签不是"注释"，是"无线导线"

**坑1：标签必须放在导线上！**

在 KiCad 中，同名标签会自动合并为同一个网络——但前提是标签附着在导线上。把标签放在空白处会导致：
```
期望：R7.p2 ═══ SW2.p1 ═══ [KEY1标签] ═══ H1.p24  ← 都是同一条网
实际：R7.p2 ─ SW2.p1（net A）       [KEY1]孤悬（net B）  H1.p24（net C）
```
三条独立的网，KiCad 不知道它们要连在一起。**解决方案：把标签直接放在元件之间的导线段上，导线高亮后再放下。**

**坑2：按键消抖电路的正确拓扑**

电路要求：R（上拉）+ C（消抖）+ SW（按键）+ MCU脚 → 四者在同一节点。

错误接法（常见）：
```
+3.3V → R → [SW一脚] ─║─ [SW另一脚 + C + MCU]  ← MCU在开关后面！
```
不按时MCU脚悬空，读到随机值。

正确接法：
```
+3.3V → R → [R + C + SW一脚 + MCU]  ← 全部在同一交汇点
                    │
                  SW另一脚 → GND
```
这是经典的"上拉+消抖"按键电路，电子设计中几乎每个项目都会遇到。

**坑3：消抖电容必须接地，不是 No-Connect**

C18/C19/C20 的负极必须接 GND，不能放 No-Connect 标记。放了 × 号 ERC 不报错但电容不工作，按键会抖动。**ERC 清除 ≠ 电路正确。**

**坑4：ERC 错误数量不代表电路质量**

ERC 从 82 逐步降至 6：
- 82 → 74：修复标签悬空（5个）+ 电容接地（3个）
- 74 → 69：修复电源标签（5个）
- 69 → 6：补 C21 接线 + H1/H2 空脚加 No-Connect（~60个）+ 按键拓扑修正

剩余的 6 个是电源声明问题（`power_pin_not_driven`），因为板子由 Blue Pill 核心板供电而非自带电源芯片，这不影响功能。

### 💡 原理图检查清单方法

逐信号网络对照引脚分配表验证，是最可靠的检查方法。15 条信号线全部手动核对：
PA0→DHT22, PA4→KEY1, PA5→KEY2, PA6→KEY3, PB0→HC_TRIG, PB1→HC_ECHO,
PB6→I2C_SCL, PB7→I2C_SDA, PA9→ESP_TX, PA10→ESP_RX, PB12→LED_R,
PB13→LED_Y, PB14→LED_G, PB15→BUZZ, ESP_RST→J5.p4

全部 15 条通过后，原理图才算真正完成。

---

## 📅 2026-07-18 — P8: PCB 导入 + 封装修复

### 💡 原理图 → PCB 的第一步：封装必须 100% 匹配

F8 导入时 14 个元件报错（11 电阻 + 3 按键），根因是**原理图中的封装名与 KiCad 库中实际文件名不匹配**。

**坑5：Python 脚本生成的封装名不完整**

电阻的封装名 `R_Axial_DIN0207_L6.3mm_D2.5mm` 缺了脚距和方向后缀。KiCad 10 库中实际文件名为 `R_Axial_DIN0207_L6.3mm_D2.5mm_P2.54mm_Vertical`。

按键的封装名 `SW_TH_4P_5x5mm` 在 KiCad 10 标准库中根本不存在，最接近的通用封装是 `SW_PUSH_6mm`（匹配 6×6mm 轻触开关）。

**教训：** 封装名必须精确到每一个后缀字符。用 KiCad 的封装预览器（Pcbnew → 工具栏 → 浏览封装）确认名称正确后再填入原理图。

**坑6：fp-lib-table 配置**

KiCad 的封装库通过 `fp-lib-table` 文件管理。我们遇到了两个问题：
1. 手动添加库时昵称拼写错误（`Button_Switch_TH` 少了最后一个 `T`）
2. 重复添加了模板中已有的库，造成冗余

KiCad 10 自带模板库表（`template/fp-lib-table`）已包含所有标准库，一般情况下不需要手动添加。**如果添加，务必确认昵称与库文件夹名完全一致。**

**修复方法：** 直接编辑原理图 `.kicad_sch` 文件，用 sed 批量替换错误封装名，备好份后再替换。

### 💡 KiCad 学习门槛总结

今天从零开始学 KiCad 遇到的问题按频率排序：

| 频率 | 问题类型 | 典型例子 |
|---|---|---|
| 🔥🔥🔥 | 标签/网络概念 | 标签放空白处 = 死网络 |
| 🔥🔥 | 电路拓扑 | 按键 R+C+SW+MCU 交汇点 |
| 🔥 | 封装名不匹配 | 电阻缺脚距、按键名不存在 |
| 🔥 | 库表配置 | fp-lib-table 昵称/路径 |

**核心经验：** KiCad 的所有"自动"功能（标签合并、ERC、封装匹配）都需要输入精确——一个字符的差异就会导致失败。这和写代码一样，"语法正确"是"功能正确"的前提。

---

## 📅 2026-07-19（晚）— P8: PCB 布局微调 + 布线

### 💡 布局微调：消抖电容靠近按键

C18/C19/C20 是按键消抖电容（100nF），必须紧邻对应按键 SW2/SW3/SW4。移动前三组电容和按键 Y 方向差了 10mm（不同"行"），移动后 Y 差距缩小到 ~1mm，X 方向保持 11mm 左右——消抖电容离按键越近，消抖效果越好。

### 💡 电源走线：从源头出发

+5V 源自 Blue Pill H2 Pad 35（USB 5V 经核心板引出），经过 HC-SR04(J4) → 滤波电容(C21) → 蜂鸣器(LS1)。从源头出发、沿最近路径依次串联，避免星型拓扑。

由于是本项目是双面 THT 板（无贴片），所有走线都在顶层(F.Cu)，无需过孔。

### 💡 GND 铺铜：PCB 设计的标准终点

GND 不需要一根根手连——用 Copper Pour 铺铜自动连接所有 GND 焊盘。双面铺铜（F.Cu + B.Cu）提供低阻抗回流路径和 EMI 屏蔽。关键步骤：
1. 切换到目标层（B.Cu）
2. 添加 Filled Zone → 画矩形覆盖全板
3. Net 选 GND，Pad Connection 选 Solid
4. **按 B 填充所有区域**（这步最容易忘！）
5. 保存

**坑7：GND 铺铜没填充**
铺铜区域创建后只是"轮廓"，必须按 B（Fill All Zones）才能真正生成铜皮。填充前 DRC 报告 23 个 GND 相关未连接，填充后全部清除。

### 💡 布线宽度考量

全线宽 0.2mm。对最大负载（ESP8266 峰值 ~300mA），0.2mm 可承载 ~500mA（1oz 铜厚，10°C 温升）。虽然建议电源线用 0.5mm，但 0.2mm 对本板余量足够。

### 💡 DRC 验证：0 错误通过

所有 DRC 警告均为丝印重叠（R10/R11/R12 文字互碰）和封装库版本差异（H1/H2），不影响功能。**0 个未连接焊盘。**

---

## 📅 2026-07-20（凌晨）— 蜂鸣器方案紧急变更

### 💡 问题发现

PCB 完成后发现蜂鸣器实物是 3 脚有源模块（VCC/GND/IO，自带驱动三极管），而原理图设计了 2 脚排针 + NPN 三极管驱动电路（Q1+R13+R14+D5）。两者不兼容——3 脚模块插不到 2 脚排针上。

### 💡 为什么改原理图而不是改实物

- 改实物需要另买 2 脚蜂鸣器，等快递 2-3 天
- 改原理图只需删 4 个元件 + LS1 换 3 脚，半小时搞定
- 3 脚模块方案更简单（MCU 直连 IO），驱动电路冗余

### 💡 最小改动原则

只改蜂鸣器相关部分，不动其他电路：
- 删除：Q1（S8050）、R13（1k 基极限流）、R14（10k 基极下拉）、D5（1N4148 续流）
- 修改：LS1 从 2 脚 `Device:Buzzer` → 3 脚 `Connector:Conn_01x03_Pin`
- 连线：+5V → LS1 Pin1, GND → LS1 Pin2, BUZZ(MCU) → LS1 Pin3
- 元件从 31 减到 27

### 💡 改造流程

1. 备份原文件到 `backup_20260720/`
2. 原理图编辑器：删 Q1/R13/R14/D5 → 换 LS1 符号 → 加标签连线
3. PCB 编辑器：工具→从原理图更新 → 删残留封装 → LS1 换 1×03 → 重走 BUZZ → 铺铜
4. 验证：交叉分析 0 差异，DRC 0 错误

### 💡 KiCad 标签踩坑史

`/BUZZ` vs `BUZZ` 是两个不同的网路。第一次忘记斜杠前缀规则，告诉用户加 `/` 导致 H2.7 在 `BUZZ`、LS1 在 `/BUZZ`，网路分裂。交叉分析发现后修正为统一 `BUZZ`。

**教训：给用户指令前先确认实际网路名称，不要凭记忆猜测。**

### 💡 Gerber 导出 + 嘉立创准备

导出文件清单（8个）：
- 铜层：F_Cu.gbr / B_Cu.gbr
- 丝印：F_Silkscreen.gbr / B_Silkscreen.gbr
- 阻焊：F_Mask.gbr / B_Mask.gbr
- 边框：Edge_Cuts.gbr
- 钻孔：PTH.drl（镀铜孔，NPTH 不需要）

嘉立创参数：FR-4，2层，1.6mm，80×60mm，绿色阻焊。

---

## 📅 2026-07-20 — P8 收尾 + P9 启动：嘉立创下单

### 💡 Gerber 追加 F.Fab/B.Fab 层

原来 Gerber 只导出了 9 层（铜+丝印+阻焊+锡膏+边框），缺了 F.Fab（顶层装配图）和 B.Fab（底层装配图）。这两层标注元件轮廓和位号，厂家做焊接检查时有用。

使用 `kicad-cli pcb export gerbers` 命令行重新导出 11 层，配合 `export drill` 生成钻孔文件，打包为 `EnvMonitor_Gerber_Full.zip`。

**KiCad CLI 路径**：`%LOCALAPPDATA%\Programs\KiCad\10.0\bin\kicad-cli.exe`（KiCad 10 自带，不需要额外安装）

### 💡 嘉立创下单参数

| 参数 | 设置 |
|---|---|
| 层数 | 2 |
| 板厚 | 1.6mm |
| 尺寸 | 80×60mm |
| 板材 | FR-4 |
| 铜厚 | 1oz |
| 表面处理 | HASL（有铅喷锡） |
| 阻焊 | 绿色 |
| 最小线宽/距 | 6/6mil（本板最细 0.2mm≈8mil，满足） |

### 💡 BOM 物料清单

用 `kicad-cli sch export bom --group-by` 生成合并 BOM，27 个 PCB 焊接件（排针排母 7 + 电阻 9 + 电容 5 + LED 3 + 按键 3），加上 7 个外接模块。完整清单 → `BOM_EnvMonitor.md`。

### 💡 KiCad 分析器终检

运行了 schematic + PCB + gerber 三个核心分析器 + 交叉分析，结果：

- **5 个 Error 全部是误报/无关**：缺数据手册(DS-001)、LED 限流电阻(LR-001, 分析器不追踪排母路径)、MPN 覆盖率(SS-001)
- **3 个 Warning 全部预期内**：电源未声明源(RS-001, Blue Pill 供电)、无测试点(TE-001)
- **PCB 侧 0 Error**：布线完整，DRC 通过
- **Gerber 0 发现**：11 层完整
- **Schematic↔PCB 交叉分析 0 差异**

### 💡 文件夹清理

PCB 目录从 ~3869 文件（含大量 .history Git 历史、旧版工程、Python 生成脚本、重复分析输出）精简到 20+ 文件：

```
hardware/pcb/
├── 接线手册.md
└── EnvMonitor/
    ├── *.kicad_*           ← 核心设计文件
    ├── BOM_EnvMonitor.md    ← 物料清单
    ├── EnvMonitor_Gerber_Full.zip ← 最终 Gerber
    ├── gerber/              ← Gerber 源文件(13个)
    ├── analysis/            ← 出厂检查报告
    └── backup_20260720/     ← 蜂鸣器改版前备份
```

**教训：开发过程中的中间文件（Python 脚本、测试工程、旧版 Gerber）完成任务后及时清理，否则 1 周后自己都分不清哪个是最新版。**

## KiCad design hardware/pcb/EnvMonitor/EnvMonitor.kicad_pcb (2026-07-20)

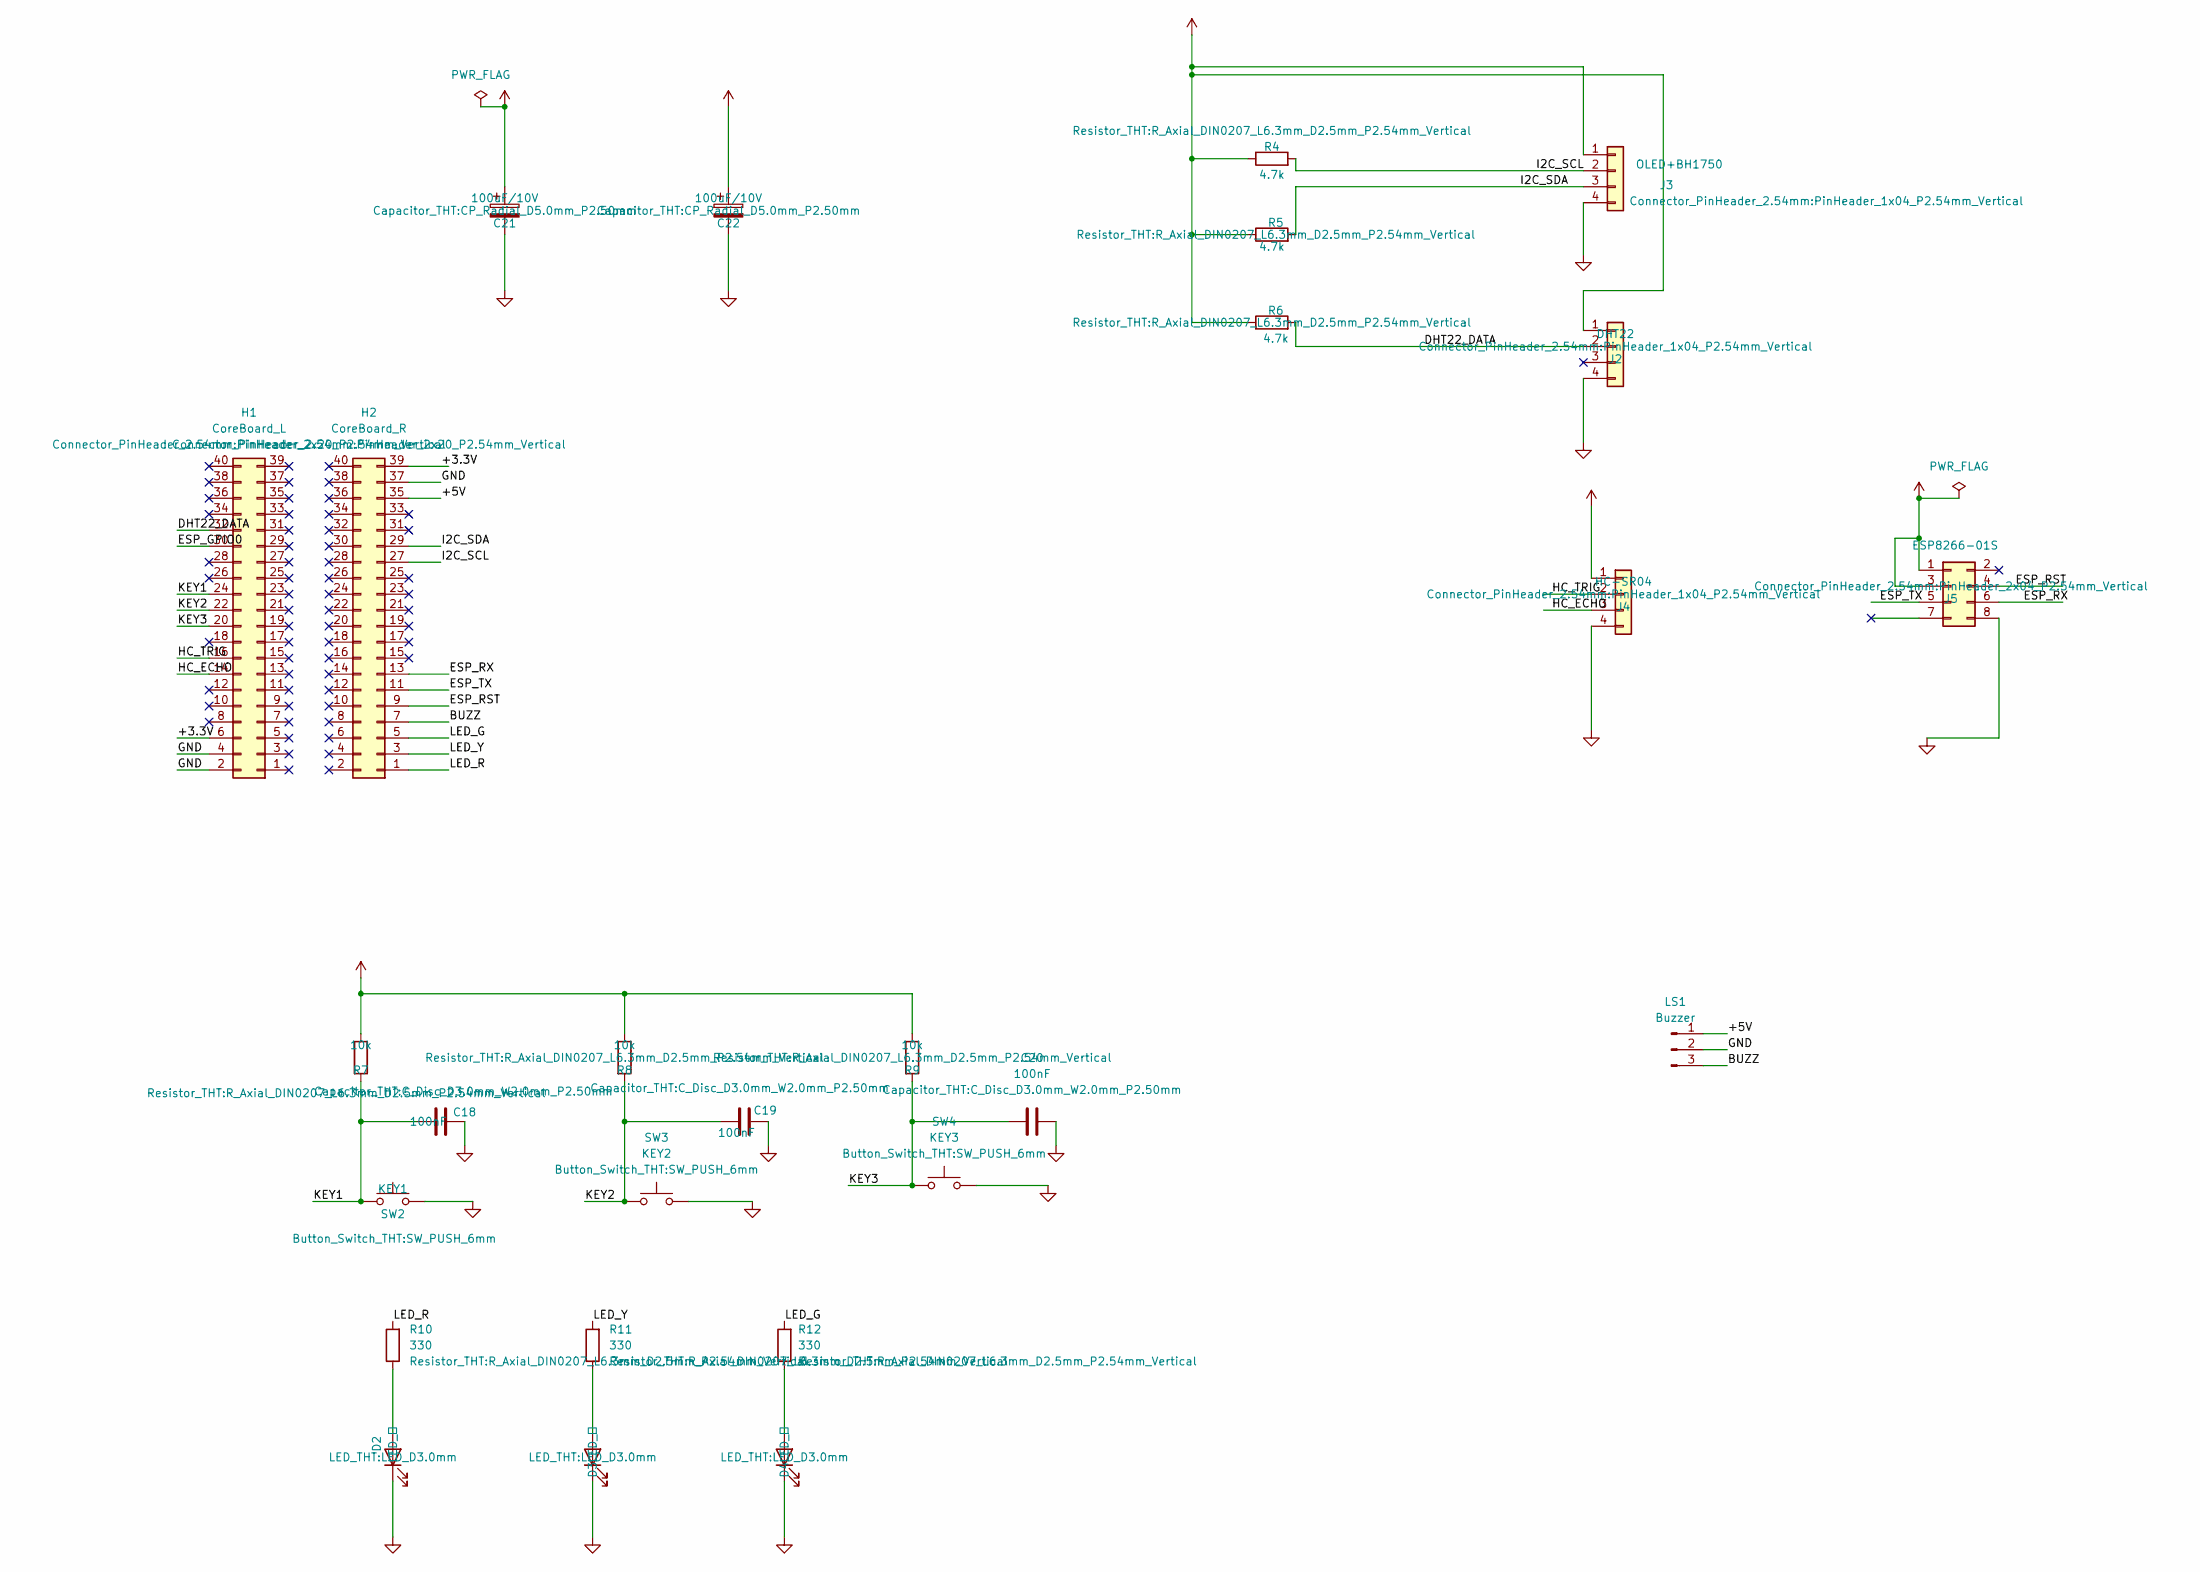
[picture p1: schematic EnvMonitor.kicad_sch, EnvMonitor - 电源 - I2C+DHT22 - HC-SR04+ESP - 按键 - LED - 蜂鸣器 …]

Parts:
C18, C19, C20: 100nF; C_Disc_D3.0mm_W2.0mm_P2.50mm
C21, C22: 100uF/10V; CP_Radial_D5.0mm_P2.50mm
D2: LED_红; LED_D3.0mm
D3: LED_黄; LED_D3.0mm
D4: LED_绿; LED_D3.0mm
H1: CoreBoard_L; PinHeader_2x20_P2.54mm_Vertical
H2: CoreBoard_R; PinHeader_2x20_P2.54mm_Vertical
J2: DHT22; PinHeader_1x04_P2.54mm_Vertical
J3: OLED+BH1750; PinHeader_1x04_P2.54mm_Vertical
J4: HC-SR04; PinHeader_1x04_P2.54mm_Vertical
J5: ESP8266-01S; PinHeader_2x04_P2.54mm_Vertical
LS1: Buzzer; PinHeader_1x03_P2.54mm_Vertical
R4, R5, R6: 4.7k; R_Axial_DIN0207_L6.3mm_D2.5mm_P2.54mm_Vertical
R7, R8, R9: 10k; R_Axial_DIN0207_L6.3mm_D2.5mm_P2.54mm_Vertical
R10, R11, R12: 330; R_Axial_DIN0207_L6.3mm_D2.5mm_P2.54mm_Vertical
SW2: KEY1; SW_PUSH_6mm
SW3: KEY2; SW_PUSH_6mm
SW4: KEY3; SW_PUSH_6mm

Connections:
+3.3V: C22.1, H1.6, H2.39, J2.1, J3.1, J5.1, J5.3, R4.1, R5.1, R6.1, R7.1, R8.1, R9.1
+5V: C21.1, H2.35, J4.1, LS1.1
/BUZZ: H2.7, LS1.3
/DHT22_DATA: H1.32, J2.2, R6.2
/ESP_GPIO0: H1.30
/ESP_RST: H2.9, J5.4
/ESP_RX: H2.13, J5.6
/ESP_TX: H2.11, J5.5
/HC_ECHO: H1.14, J4.3
/HC_TRIG: H1.16, J4.2
/I2C_SCL: H2.27, J3.2, R4.2
/I2C_SDA: H2.29, J3.3, R5.2
/KEY1: C18.1, H1.24, R7.2, SW2.1
/KEY2: C19.1, H1.22, R8.2, SW3.1
/KEY3: C20.1, H1.20, R9.2, SW4.1
/LED_G: H2.5, R12.2
/LED_R: H2.1, R10.2
/LED_Y: H2.3, R11.2
GND: C18.2, C19.2, C20.2, C21.2, C22.2, D2.1 (K), D3.1 (K), D4.1 (K), H1.2, H1.4, H2.37, J2.4, J3.4, J4.4, J5.8, LS1.2, SW2.2, SW3.2, SW4.2
unnamed: D2.2 (A), R10.1
unnamed: D3.2 (A), R11.1
unnamed: D4.2 (A), R12.1

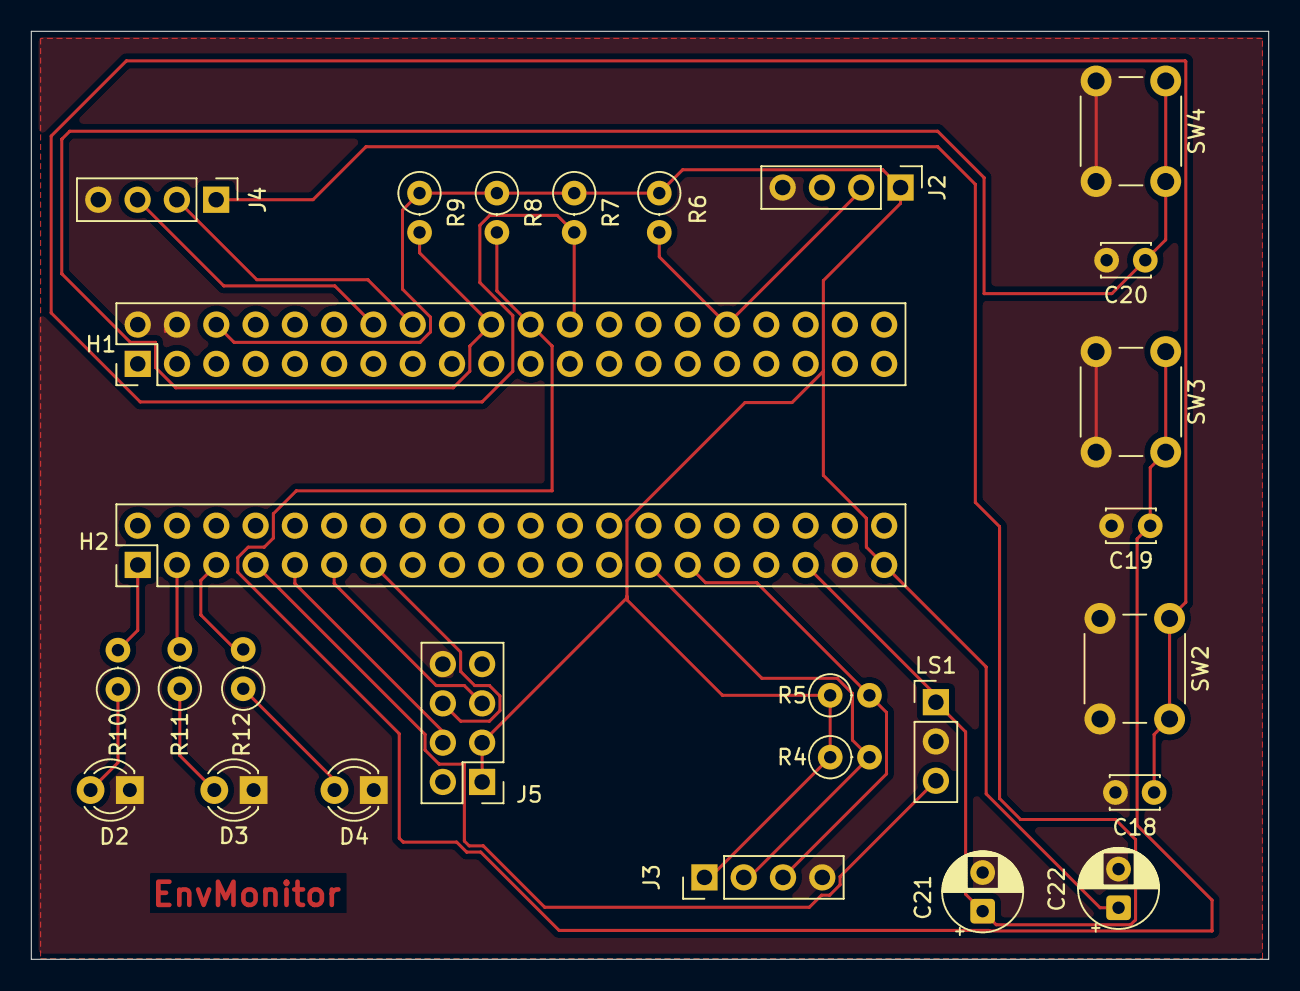
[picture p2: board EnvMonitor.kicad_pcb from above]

Board: 2 copper layers, 80.0 x 60.0 mm, 27 parts (0 on the bottom side), 21 nets.

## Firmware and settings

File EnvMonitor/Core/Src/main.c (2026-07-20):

/**
 * @file    main.c
 * @brief   智能环境监测与物联网控制站 — FreeRTOS 版本
 * @note    6 个任务替代裸机超级循环:
 *          SensorTask(3) / AlarmTask(3) / DisplayTask(2) /
 *          ButtonTask(2) / BuzzerTask(2) / CloudTask(1)
 *
 *          资源保护: I2C_Mutex / Data_Mutex / UART_Mutex
 *          任务通信: ButtonQueue / BuzzerQueue
 */

#include "main.h"

/* ==================== 全局变量 ==================== */
SensorData_t g_sensorData = {0};
volatile uint32_t g_sysTick = 0;

/* ==================== 主函数 ==================== */
int main(void)
{
    /* HAL 初始化 */
    HAL_Init();

    /* 系统时钟 72MHz */
    SystemClock_Config();

    /* 外设初始化（CubeMX 生成） */
    MX_GPIO_Init();
    MX_I2C1_Init();
    MX_TIM3_Init();
    MX_USART1_UART_Init();

    /* 驱动层初始化 */
    OLED_Init();
    DHT22_Init();
    BH1750_Init();
    SR04_Init();
    ESP8266_Init();
    Button_Init();
    Buzzer_Init();
    LED_Init();

    /* 启动画面 */
    OLED_ShowString(0, 2, "Env Monitor v2.0", 0);
    OLED_ShowString(0, 4, "FreeRTOS Starting", 0);
    OLED_Refresh();
    HAL_Delay(1500);
    OLED_Clear();

    /* 共享资源初始化（互斥量 + 队列） */
    TaskShared_Init();

    /* ========== 创建 RTOS 任务 ========== */
    BaseType_t ret;

    /* --- SensorTask (prio=3, 5s周期) --- */
    ret = xTaskCreate(SensorTask_Run,
                      "Sensor",
                      SENSOR_TASK_STACK_SIZE,
                      NULL,
                      SENSOR_TASK_PRIORITY,
                      NULL);
    configASSERT(ret == pdPASS);

    /* --- AlarmTask (prio=3, 500ms周期) --- */
    ret = xTaskCreate(AlarmTask_Run,
                      "Alarm",
                      ALARM_TASK_STACK_SIZE,
                      NULL,
                      ALARM_TASK_PRIORITY,
                      NULL);
    configASSERT(ret == pdPASS);

    /* --- DisplayTask (prio=2, 1s周期) --- */
    ret = xTaskCreate(DisplayTask_Run,
                      "Display",
                      DISPLAY_TASK_STACK_SIZE,
                      NULL,
                      DISPLAY_TASK_PRIORITY,
                      NULL);
    configASSERT(ret == pdPASS);

    /* --- ButtonTask (prio=2, 20ms周期) --- */
    ret = xTaskCreate(ButtonTask_Run,
                      "Button",
                      BUTTON_TASK_STACK_SIZE,
                      NULL,
                      BUTTON_TASK_PRIORITY,
                      NULL);
    configASSERT(ret == pdPASS);

    /* --- BuzzerTask (prio=2, 队列驱动) --- */
    ret = xTaskCreate(BuzzerTask_Run,
                      "Buzzer",
                      BUZZER_TASK_STACK_SIZE,
                      NULL,
                      BUZZER_TASK_PRIORITY,
                      NULL);
    configASSERT(ret == pdPASS);

    /* --- CloudTask (prio=1, 最低, 60s周期) --- */
    ret = xTaskCreate(CloudTask_Run,
                      "Cloud",
                      CLOUD_TASK_STACK_SIZE,
                      NULL,
                      CLOUD_TASK_PRIORITY,
                      NULL);
    configASSERT(ret == pdPASS);

    /* ========== 启动调度器（永不返回） ========== */
    vTaskStartScheduler();

    /* 理论上不会到这里，但如果发生则进入错误处理 */
    Error_Handler();
    return 0;
}

/* ==================== 系统时钟配置 ==================== */
/**
 * @brief  HSE(8MHz) → PLL(×9) → SYSCLK(72MHz)
 */
void SystemClock_Config(void)
{
    RCC_OscInitTypeDef RCC_OscInitStruct = {0};
    RCC_ClkInitTypeDef RCC_ClkInitStruct = {0};

    RCC_OscInitStruct.OscillatorType = RCC_OSCILLATORTYPE_HSE;
    RCC_OscInitStruct.HSEState = RCC_HSE_ON;
    RCC_OscInitStruct.HSEPredivValue = RCC_HSE_PREDIV_DIV1;
    RCC_OscInitStruct.HSIState = RCC_HSI_ON;
    RCC_OscInitStruct.PLL.PLLState = RCC_PLL_ON;
    RCC_OscInitStruct.PLL.PLLSource = RCC_PLLSOURCE_HSE;
    RCC_OscInitStruct.PLL.PLLMUL = RCC_PLL_MUL9;
    if (HAL_RCC_OscConfig(&RCC_OscInitStruct) != HAL_OK) {
        Error_Handler();
    }

    RCC_ClkInitStruct.ClockType = RCC_CLOCKTYPE_HCLK | RCC_CLOCKTYPE_SYSCLK
                                | RCC_CLOCKTYPE_PCLK1 | RCC_CLOCKTYPE_PCLK2;
    RCC_ClkInitStruct.SYSCLKSource = RCC_SYSCLKSOURCE_PLLCLK;
    RCC_ClkInitStruct.AHBCLKDivider = RCC_SYSCLK_DIV1;
    RCC_ClkInitStruct.APB1CLKDivider = RCC_HCLK_DIV2;
    RCC_ClkInitStruct.APB2CLKDivider = RCC_HCLK_DIV1;

    if (HAL_RCC_ClockConfig(&RCC_ClkInitStruct, FLASH_LATENCY_2) != HAL_OK) {
        Error_Handler();
    }
}

/* ==================== 错误处理 ==================== */
void Error_Handler(void)
{
    __disable_irq();
    while (1) {
        HAL_GPIO_TogglePin(LED_RED_PORT, LED_RED_PIN);
        for (volatile uint32_t i = 0; i < 500000; i++) { __NOP(); }
    }
}

#ifdef USE_FULL_ASSERT
void assert_failed(uint8_t *file, uint32_t line)
{
    printf("Assert failed: %s, line %lu\r\n", file, line);
    Error_Handler();
}
#endif

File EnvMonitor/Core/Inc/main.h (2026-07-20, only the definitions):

#define I2C_BUS                     hi2c1
#define DHT22_PORT                  GPIOA
#define DHT22_PIN                   GPIO_PIN_0
#define SR04_TRIG_PORT              GPIOB
#define SR04_TRIG_PIN               GPIO_PIN_0
#define SR04_ECHO_PORT              GPIOB
#define SR04_ECHO_PIN               GPIO_PIN_1
#define SR04_TIM                    (&htim3)
#define SR04_TIM_CHANNEL            TIM_CHANNEL_4
#define ESP_UART                    huart1
#define KEY1_PORT                   GPIOA
#define KEY1_PIN                    GPIO_PIN_4
#define KEY2_PORT                   GPIOA
#define KEY2_PIN                    GPIO_PIN_5
#define KEY3_PORT                   GPIOA
#define KEY3_PIN                    GPIO_PIN_6
#define LED_RED_PORT                GPIOB
#define LED_RED_PIN                 GPIO_PIN_12
#define LED_YELLOW_PORT             GPIOB
#define LED_YELLOW_PIN              GPIO_PIN_13
#define LED_GREEN_PORT              GPIOB
#define LED_GREEN_PIN               GPIO_PIN_14
#define BUZZER_PORT                 GPIOB
#define BUZZER_PIN                  GPIO_PIN_15
#define SENSOR_SAMPLE_INTERVAL_MS   5000U
#define CLOUD_UPLOAD_INTERVAL_MS    60000U
#define OLED_REFRESH_INTERVAL_MS    1000U
#define ALARM_CHECK_INTERVAL_MS     500U
#define ALARM_TEMP_HIGH             30.0f
#define ALARM_HUMI_LOW              30.0f
#define ALARM_DIST_CLOSE            20.0f

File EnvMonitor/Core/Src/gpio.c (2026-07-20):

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

/* Includes ------------------------------------------------------------------*/
#include "gpio.h"

/*----------------------------------------------------------------------------*/
/* Configure GPIO                                                             */
/*----------------------------------------------------------------------------*/
/** Configure pins as
        * Analog
        * Input
        * Output
        * EVENT_OUT
        * EXTI
*/
void MX_GPIO_Init(void)
{

  GPIO_InitTypeDef GPIO_InitStruct = {0};

  /* GPIO Ports Clock Enable */
  __HAL_RCC_GPIOA_CLK_ENABLE();
  __HAL_RCC_GPIOB_CLK_ENABLE();

  /*--- 初始输出电平：全部拉低 ---*/
  HAL_GPIO_WritePin(GPIOA, DHT22_PIN, GPIO_PIN_SET);       /* DHT22总线空闲=高 */
  HAL_GPIO_WritePin(GPIOB, SR04_TRIG_PIN | LED_RED_PIN | LED_YELLOW_PIN
                          | LED_GREEN_PIN | BUZZER_PIN, GPIO_PIN_RESET);

  /*--- PA0: DHT22 数据线（开漏输出，模拟1-Wire双向） ---*/
  GPIO_InitStruct.Pin = DHT22_PIN;
  GPIO_InitStruct.Mode = GPIO_MODE_OUTPUT_OD;
  GPIO_InitStruct.Pull = GPIO_PULLUP;
  GPIO_InitStruct.Speed = GPIO_SPEED_FREQ_HIGH;
  HAL_GPIO_Init(GPIOA, &GPIO_InitStruct);

  /*--- PA4/PA5/PA6: 按键输入（内部上拉，按下为低） ---*/
  GPIO_InitStruct.Pin = KEY1_PIN | KEY2_PIN | KEY3_PIN;
  GPIO_InitStruct.Mode = GPIO_MODE_INPUT;
  GPIO_InitStruct.Pull = GPIO_PULLUP;
  HAL_GPIO_Init(GPIOA, &GPIO_InitStruct);

  /*--- PB0: HC-SR04 Trig 推挽输出 ---*/
  GPIO_InitStruct.Pin = SR04_TRIG_PIN;
  GPIO_InitStruct.Mode = GPIO_MODE_OUTPUT_PP;
  GPIO_InitStruct.Pull = GPIO_PULLDOWN;
  GPIO_InitStruct.Speed = GPIO_SPEED_FREQ_LOW;
  HAL_GPIO_Init(GPIOB, &GPIO_InitStruct);

  /*--- PB12/PB13/PB14: LED红黄绿 ---*/
  GPIO_InitStruct.Pin = LED_RED_PIN | LED_YELLOW_PIN | LED_GREEN_PIN;
  GPIO_InitStruct.Mode = GPIO_MODE_OUTPUT_PP;
  GPIO_InitStruct.Pull = GPIO_NOPULL;
  GPIO_InitStruct.Speed = GPIO_SPEED_FREQ_LOW;
  HAL_GPIO_Init(GPIOB, &GPIO_InitStruct);

  /*--- PB15: 蜂鸣器 ---*/
  GPIO_InitStruct.Pin = BUZZER_PIN;
  GPIO_InitStruct.Mode = GPIO_MODE_OUTPUT_PP;
  GPIO_InitStruct.Pull = GPIO_NOPULL;
  GPIO_InitStruct.Speed = GPIO_SPEED_FREQ_LOW;
  HAL_GPIO_Init(GPIOB, &GPIO_InitStruct);

}



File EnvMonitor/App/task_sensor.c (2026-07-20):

/**
 * @file    task_sensor.c
 * @brief   SensorTask 实现 — 采集 DHT22 / BH1750 / HC-SR04 / WiFi 状态
 * @note    DHT22: 读数据时进入临界区（微秒级时序，~2ms）
 *          BH1750: 需要 I2C 互斥量
 *          HC-SR04: 定时器输入捕获，阻塞但短
 *          WiFi状态: 需要 UART 互斥量
 */

#include "main.h"
#include "task_sensor.h"
#include "task_shared.h"

void SensorTask_Run(void *pvParameters)
{
    (void)pvParameters;
    TickType_t xLastWakeTime = xTaskGetTickCount();
    float val;

    while (1) {
        vTaskDelayUntil(&xLastWakeTime, pdMS_TO_TICKS(SENSOR_SAMPLE_PERIOD_MS));

        /* 临时存储（先采集再一次性写入，减少持锁时间） */
        float temperature = 0, humidity = 0, light = 0, distance = 0;
        uint8_t wifi_ok = 0;

        /* --- DHT22: 内部已关中断保护微秒级时序（~2ms），不需额外临界区 --- */
        uint8_t dht_result = DHT22_Read(&temperature, &humidity);
        if (dht_result != DHT22_OK) {
            temperature = -999;   /* 标记无效，不更新 */
            humidity    = -999;
        }

        /* --- BH1750: I2C 互斥量 --- */
        xSemaphoreTakeRecursive(I2C_Mutex, pdMS_TO_TICKS(100));
        uint8_t bh_result = BH1750_ReadLight(&val);
        xSemaphoreGiveRecursive(I2C_Mutex);
        if (bh_result == 0) {
            light = val;
        } else {
            light = -999;
        }

        /* --- HC-SR04: 定时器捕获（无需互斥量，TIM3 独占 SR04） --- */
        if (SR04_Measure(&val) == 0) {
            distance = val;
        } else {
            distance = -999;
        }

        /* --- WiFi 状态 --- */
        xSemaphoreTakeRecursive(UART_Mutex, pdMS_TO_TICKS(50));
        wifi_ok = ESP8266_IsConnected();
        xSemaphoreGiveRecursive(UART_Mutex);

        /* --- 写入全局数据（持锁） --- */
        xSemaphoreTakeRecursive(Data_Mutex, portMAX_DELAY);
        if (temperature > -900) g_sensorData.temperature = temperature;
        if (humidity > -900)    g_sensorData.humidity    = humidity;
        if (light > -900)       g_sensorData.light       = light;
        if (distance > -900)    g_sensorData.distance    = distance;
        g_sensorData.wifi_connected = wifi_ok;
        xSemaphoreGiveRecursive(Data_Mutex);
    }
}

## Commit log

2026-07-20 🎉 Initial commit: EnvMonitor v1.0
    STM32F103C8T6 智能环境监测站
    - 裸机固件: 8 驱动 + 5 页菜单 + 报警 + ThingSpeak 上云
    - FreeRTOS: 6 任务 (Sensor/Display/Cloud/Alarm/Button/Buzzer)
    - 3 互斥量 + 2 队列任务间通信
    - KiCad PCB: 80×60mm 双面板, 27 THT 元件, 双面 GND 铺铜
    - Gerber 已导出, 嘉立创已下单
    - DHT22 + BH1750 + HC-SR04 + OLED SSD1306 + ESP8266-01S
    [EnvMonitor-B_Cu.gbl, EnvMonitor-B_Fab.gbr, EnvMonitor-B_Mask.gbs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]
2026-07-20 🧹 清理残留文件: find_kicad.ps1, Envmonitor.pdf, 旧钻孔板ZIP
2026-07-20 🙈 将每日进度移出版本控制
    [EnvMonitor.kicad_pcb, EnvMonitor.kicad_sch]
2026-07-20 💰 BOM/README 加入实际购买价格明细
    - BOM: 逐项标注立创商城实际购买价格
    - 总计: 90.02 元 (含PCB打样20元)
    - 附注: 弃用元件说明 (S8050/1N4148/AMS1117)
    - README: 更新预算为实际花费
2026-07-20 🙈 彻底排除钻孔板旧版目录
2026-07-20 📝 README: 去掉面包板描述, 新增关键问题与设计决策
2026-07-20 📝 README: 补面包板失败记录 (#9)
2026-07-20 📝 README: 新增学习历程, 从标准库到HAL/FreeRTOS/KiCad
2026-07-20 📝 PROGRESS: ThingSpeak配置/ESP测试/CH340故障记录
2026-07-20 🐛 固件代码审查修复: DHT22死锁 + 中断冲突 + UART竞争 + 密码保护
    - 🔴 dht22.c: HAL_Delay(2)在关中断后调用导致死锁 → 改用DHT22_DELAY_US忙等
    - 🟡 task_sensor.c: 去掉DHT22外层的taskENTER_CRITICAL (内部已关中断)
    - 🟡 task_display.c: WiFi重连补UART_Mutex防数据竞争
    - 🟢 esp8266.h: WiFi密码迁移至secrets.h (gitignored), 新增secrets_template.h
    - 📝 PROGRESS: ESP8266 AT测试全部通过, HTTP数据上云200 OK
    - 📝 PROGRESS: CH340供电不足踩坑记录
    [dht22.c, task_display.c, task_sensor.c]

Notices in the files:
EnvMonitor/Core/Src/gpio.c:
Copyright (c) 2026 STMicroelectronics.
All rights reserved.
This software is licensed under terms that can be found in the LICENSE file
